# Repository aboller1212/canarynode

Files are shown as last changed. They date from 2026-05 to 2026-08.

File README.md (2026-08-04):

# CANaryNode

A CAN FD sensor node built around an STM32G474. It reads an IMU and an
environmental sensor and puts the data on a CAN bus. The firmware is
bare-metal — no HAL, no generated code, just CMSIS headers and the
reference manual. I'm building it this way because I want to understand
what every peripheral is actually doing at the register level, not call
somebody's library function and hope.

## Hardware

The custom board is a 4-layer PCB with:

- STM32G474RCT6 (Cortex-M4F, 256K flash)
- BMI270 IMU on SPI
- BME280 temperature/pressure/humidity sensor on I2C
- TI TCAN CAN FD transceiver
- USB-C

Most of the driver work was done on a Nucleo-G474RE first, bringing up one
peripheral at a time, so that porting to the real board would mostly be
remapping pins. The custom board is here now and boots.

A couple of things differ between the two: the Nucleo has a G474RET6 (512K
flash) and routes CAN to FDCAN1 on PA11/PA12, while my board uses an RCT6
and puts CAN on PB5/PB6, which is FDCAN2. That's an instance swap, not just
a pin change, so it needs its own message RAM offset.

## Layout

- `firmware/` — the STM32 firmware, where most of the work is
- `hardware/` — schematic and board files
- `docs/` — datasheets and my bring-up notes
- `tools/` — scripts

## Building

CMake + Ninja with the arm-none-eabi GCC toolchain.

    cd firmware
    cmake -B build -G Ninja
    cmake --build build

Produces `build/canary_firmware` (ELF) and a `.bin` next to it.

## Flashing

Two ways, depending on the board.

On the Nucleo I use an external ST-Link V2 on SWD (SWDIO to PA13, SWCLK to
PA14, plus GND and 3V3). The onboard ST-Link V3E doesn't work reliably from
an Apple Silicon Mac, so its USB stays unplugged and the target gets power
from the V2.

The custom board can be programmed over USB with no debugger at all. The
STM32 has a bootloader burned into ROM — jumper BOOT0 high, plug in USB-C,
and it enumerates as a DFU device:

    STM32_Programmer_CLI -c port=USB1 -w build/canary_firmware.bin 0x08000000

Pull the jumper and power cycle to run the firmware instead. That's handy,
but DFU only programs — for actual debugging I use OpenOCD as a GDB server
with arm-none-eabi-gdb over SWD.

## Status

Working and verified on hardware:

- LED blink and a TIM6 timer interrupt
- I2C master and the full BME280 driver — chip ID, calibration read and
  reassembly, and Bosch's compensation math. It streams real temperature,
  pressure and humidity, and the humidity climbs when you breathe on it.
- FDCAN at 500 kbit/s in internal loopback. A frame goes out, loops through
  the peripheral's message RAM, and comes back byte for byte.
- The custom board itself: it powers up, enumerates over USB, and takes a
  verified flash write.

Written and compiling, not yet tested on hardware:

- SPI master driver
- BMI270 driver, including the 8 KB configuration blob the sensor needs
  uploaded before it will do anything

Not working yet:

- CAN on a real bus. The MCU side is fine — I can see it transmitting
  cleanly in the registers — but the transceiver breakout I bought has a
  10k resistor on its slew rate pin that caps it well below 500 kbit/s.
  Waiting on a different transceiver.

## What's left

Port the pin assignments to the custom board, get the BMI270 talking, pack
sensor readings into CAN frames, and get those frames onto a real bus.

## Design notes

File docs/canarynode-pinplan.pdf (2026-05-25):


24/05/2026

canarynode-pinplan Project Configuration Report

## 1. Description

### 1.1. Project

Project Name | canarynode-pinplan
Board Name | custom
Generated with: | STM32CubeMX 6.15.0
Date | 05/24/2026

### 1.2. MCU

MCU Series | STM32G4
MCU Line | STM32G4x4
MCU name | STM32G474RETx
MCU Package | LQFP64
MCU Pin number | 64

### 1.3. Core(s) information

Core(s) | ARM Cortex-M4

## 2. Pinout Configuration

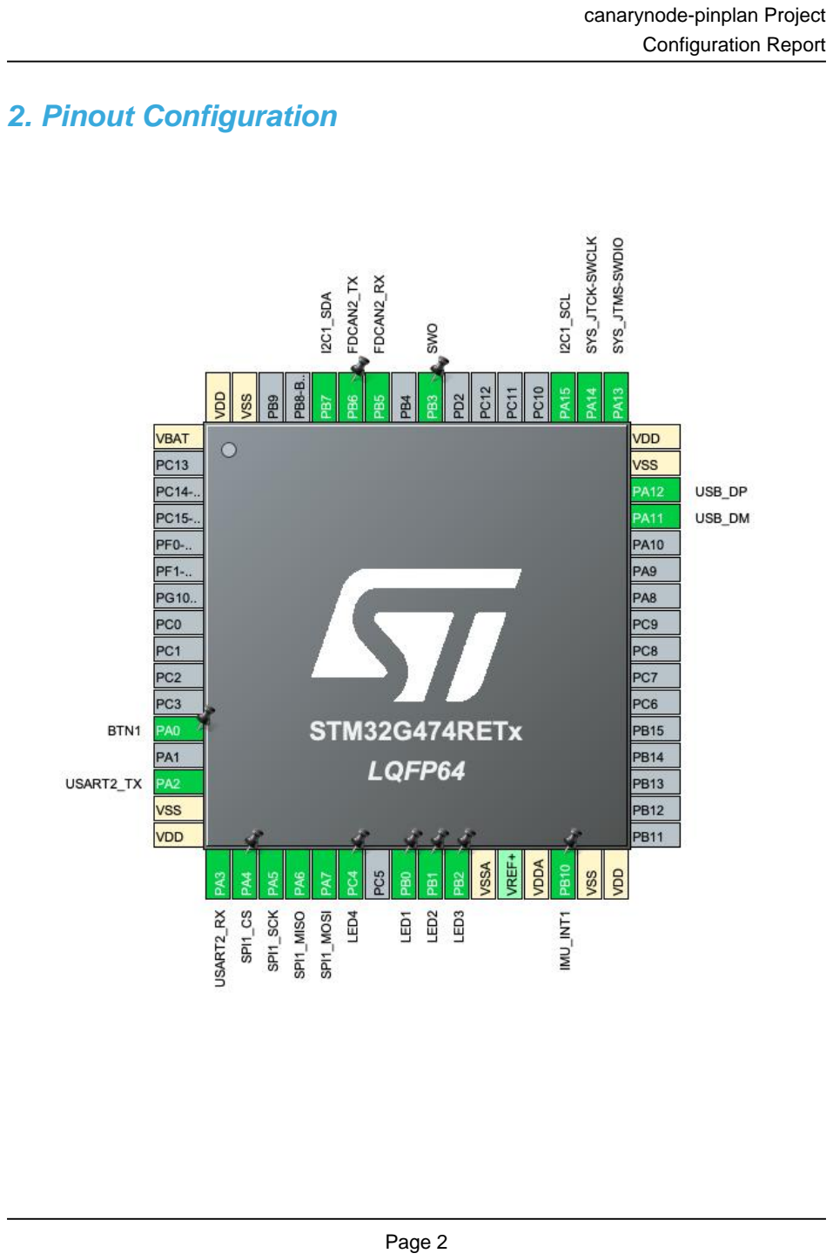
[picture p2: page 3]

## 3. Pins Configuration

Pin Number LQFP64 | Pin Name (function after reset) | Pin Type | Alternate Function(s) | Label
1 | VBAT | Power
12 | PA0 | I/O | GPIO_EXTI0 | BTN1
14 | PA2 | I/O | USART2_TX
15 | VSS | Power
16 | VDD | Power
17 | PA3 | I/O | USART2_RX
18 | PA4 * | I/O | GPIO_Output | SPI1_CS
19 | PA5 | I/O | SPI1_SCK
20 | PA6 | I/O | SPI1_MISO
21 | PA7 | I/O | SPI1_MOSI
22 | PC4 * | I/O | GPIO_Output | LED4
24 | PB0 * | I/O | GPIO_Output | LED1
25 | PB1 * | I/O | GPIO_Output | LED2
26 | PB2 * | I/O | GPIO_Output | LED3
27 | VSSA | Power
29 | VDDA | Power
30 | PB10 | I/O | GPIO_EXTI10 | IMU_INT1
31 | VSS | Power
32 | VDD | Power
45 | PA11 | I/O | USB_DM
46 | PA12 | I/O | USB_DP
47 | VSS | Power
48 | VDD | Power
49 | PA13 | I/O | SYS_JTMS-SWDIO
50 | PA14 | I/O | SYS_JTCK-SWCLK
51 | PA15 | I/O | I2C1_SCL
56 | PB3 | I/O | SYS_JTDO-SWO | SWO
58 | PB5 | I/O | FDCAN2_RX
59 | PB6 | I/O | FDCAN2_TX
60 | PB7 | I/O | I2C1_SDA
63 | VSS | Power
64 | VDD | Power

* The pin is affected with an I/O function

## 4. Clock Tree Configuration

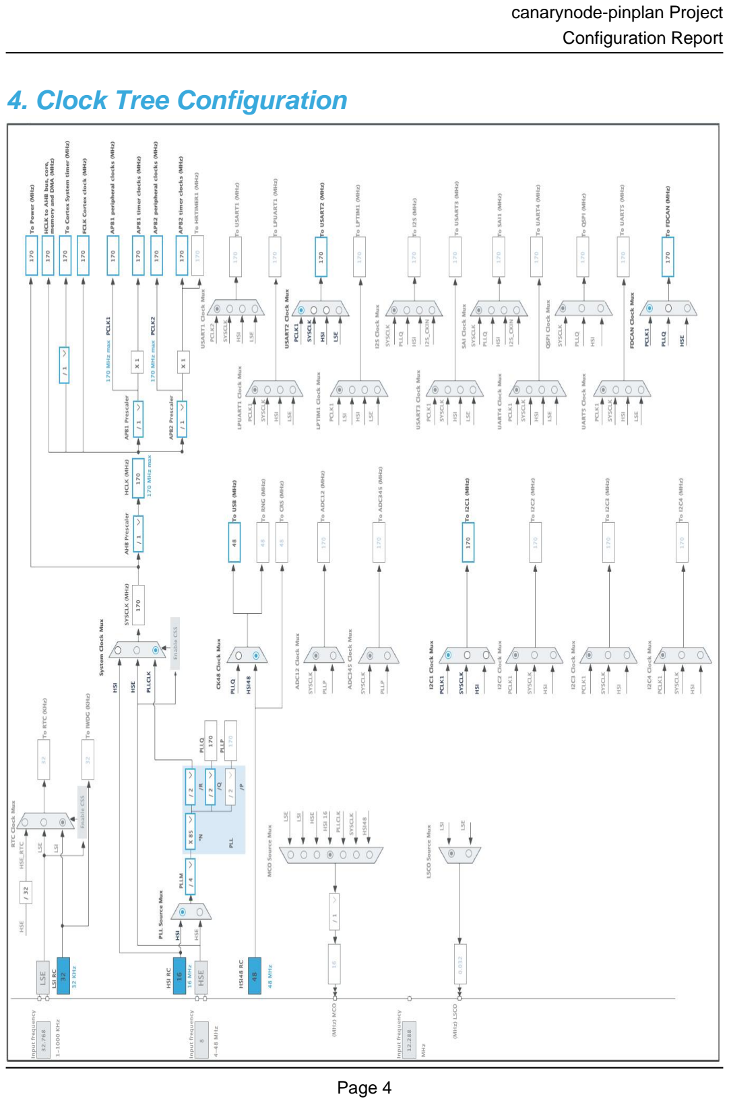
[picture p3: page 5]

## 1. Power Consumption Calculator report

### 1.1. Microcontroller Selection

Series | STM32G4
Line | STM32G4x4
MCU | STM32G474RETx
Datasheet | DS12288_Rev0

### 1.2. Parameter Selection

Temperature | 25
Vdd | 3.0

### 1.3. Battery Selection

Battery | Li-SOCL2(A3400)
Capacity | 3400.0 mAh
Self Discharge | 0.08 %/month
Nominal Voltage | 3.6 V
Max Cont Current | 100.0 mA
Max Pulse Current | 200.0 mA
Cells in series | 1
Cells in parallel | 1

### 1.4. Sequence

Step | Step1 | Step2
Mode | RUN | STOP1
Vdd | 3.0 | 3.0
Voltage Source | Battery | Battery
Range | Range1-Boost | NoRange
Fetch Type | FLASH/DualBank/ART | NA
CPU Frequency | 170 MHz | 0 Hz
Clock Configuration | HSE BYP PLL | ALL CLOCKS OFF
Clock Source Frequency | 4 MHz | 0 Hz
Peripherals
Additional Cons. | 0 mA | 0 mA
Average Current | 29.5 mA | 80.5 µA
Duration | 0.1 ms | 0.9 ms
DMIPS | 213.0 | 0.0
Ta Max | 124.25 | 129.98
Category | In DS Table | In DS Table

### 1.5. Results

Sequence Time | 1 ms | Average Current | 3.02 mA
Battery Life | 1 month, 16 days, 9 hours | Average DMIPS | 212.5 DMIPS

### 1.6. Chart

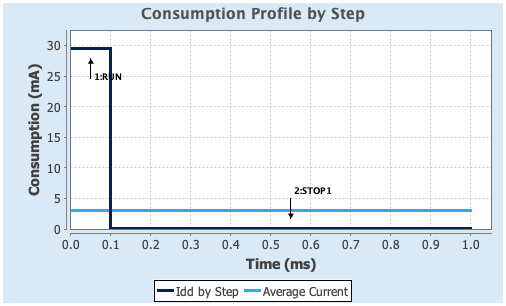
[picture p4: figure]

## 2. Software Project

### 2.1. Project Settings

Name | Value
Project Name | canarynode-pinplan
Project Folder | /Users/alexboller/STM32CubeIDE/workspace_1.19.0/canarynode-pinplan
Toolchain / IDE | STM32CubeIDE
Firmware Package Name and Version | STM32Cube FW_G4 V1.6.3
Application Structure | Advanced
Generate Under Root | Yes
Do not generate the main() | No
Minimum Heap Size | 0x200
Minimum Stack Size | 0x400

### 2.2. Code Generation Settings

Name | Value
STM32Cube MCU packages and embedded software | Copy only the necessary library files
Generate peripheral initialization as a pair of '.c/.h' files | No
Backup previously generated files when re-generating | No
Keep User Code when re-generating | Yes
Delete previously generated files when not re-generated | Yes
Set all free pins as analog (to optimize the power consumption) | No
Enable Full Assert | No

### 2.3. Advanced Settings - Generated Function Calls

Rank | Function Name | Peripheral Instance Name
1 | SystemClock_Config | RCC
2 | MX_GPIO_Init | GPIO
3 | MX_I2C1_Init | I2C1
4 | MX_SPI1_Init | SPI1
5 | MX_USART2_UART_Init | USART2
6 | MX_USB_PCD_Init | USB
7 | MX_FDCAN2_Init | FDCAN2

## 3. Peripherals and Middlewares Configuration

### 3.1. FDCAN2

mode: Activated
3.1.1. Parameter Settings:

Basic Parameters:

Clock Divider | Divide kernel clock by 1
Frame Format | Classic mode
Mode | Normal mode
Auto Retransmission | Disable
Transmit Pause | Disable
Protocol Exception | Disable
Nominal Sync Jump Width | 1
Data Prescaler | 1
Data Sync Jump Width | 1
Data Time Seg1 | 1
Data Time Seg2 | 1
Std Filters Nbr | 0
Ext Filters Nbr | 0
Tx Fifo Queue Mode | FIFO mode
Bit Timings Parameters:
Nominal Prescaler | 16
Nominal Time Quantum | 94.11764705882354 *
Nominal Time Seg1 | 1
Nominal Time Seg2 | 1
Nominal Time for one Bit | 282 *
Nominal Baud Rate | 3541666 *

### 3.2. I2C1

I2C: I2C
3.2.1. Parameter Settings:

Timing configuration:

Custom Timing | Disabled
I2C Speed Mode | Standard Mode
I2C Speed Frequency (KHz) | 100
Rise Time (ns) | 100
Fall Time (ns) | 100

Coefficient of Digital Filter | 0
Analog Filter | Enabled
Timing | 0x40B285C2 *
Slave Features:
Clock No Stretch Mode | Disabled
General Call Address Detection | Disabled
Primary Address Length selection | 7-bit
Dual Address Acknowledged | Disabled
Primary slave address | 0

### 3.3. RCC

3.3.1. Parameter Settings:

System Parameters:

VDD voltage (V) | 3.3
Instruction Cache | Enabled
Prefetch Buffer | Disabled
Data Cache | Enabled
Flash Latency(WS) | 4 WS (5 CPU cycle)
RCC Parameters:
HSI Calibration Value | 64
HSE Startup Timout Value (ms) | 100
LSE Startup Timout Value (ms) | 5000
Power Parameters:
Power Regulator Voltage Scale | Power Regulator Voltage Scale 1 boost
Peripherals Clock Configuration:
Generate the peripherals clock configuration | TRUE

### 3.4. SPI1

Mode: Full-Duplex Master
3.4.1. Parameter Settings:

Basic Parameters:

Frame Format | Motorola
Data Size | 8 Bits *
First Bit | MSB First
Clock Parameters:

Prescaler (for Baud Rate) | 32 *
Baud Rate | 5.3125 MBits/s *
Clock Polarity (CPOL) | High *
Clock Phase (CPHA) | 2 Edge *
Advanced Parameters:
CRC Calculation | Disabled
NSS Signal Type | Software

### 3.5. SYS

Debug: Trace Asynchronous Sw
Timebase Source: SysTick
mode: save power of non-active UCPD - deactive Dead Battery pull-up

### 3.6. USART2

Mode: Asynchronous
3.6.1. Parameter Settings:

Basic Parameters:

Baud Rate | 115200
Word Length | 8 Bits (including Parity)
Parity | None
Stop Bits | 1
Advanced Parameters:
Data Direction | Receive and Transmit
Over Sampling | 16 Samples
Single Sample | Disable
ClockPrescaler | 1
Fifo Mode | Disable
Txfifo Threshold | 1 eighth full configuration
Rxfifo Threshold | 1 eighth full configuration
Advanced Features:
Auto Baudrate | Disable
TX Pin Active Level Inversion | Disable
RX Pin Active Level Inversion | Disable
Data Inversion | Disable
TX and RX Pins Swapping | Disable
Overrun | Enable
DMA on RX Error | Enable

MSB First | Disable

### 3.7. USB

mode: Device (FS)
3.7.1. Parameter Settings:

Basic Parameters:

Speed | Full Speed 12MBit/s
Physical interface | Internal Phy
Sof Enable | Disabled
Power Parameters:
Low Power | Disabled
Link Power Management | Disabled
Battery Charging | Disabled

* User modified value

## 4. System Configuration

### 4.1. GPIO configuration

IP | Pin | Signal | GPIO mode | GPIO pull/up pull down | Max Speed | User Label
FDCAN2 | PB5 | FDCAN2_RX | Alternate Function Push Pull | No pull-up and no pull-down | Low
| PB6 | FDCAN2_TX | Alternate Function Push Pull | No pull-up and no pull-down | Low
I2C1 | PA15 | I2C1_SCL | Alternate Function Open Drain | No pull-up and no pull-down | Low
| PB7 | I2C1_SDA | Alternate Function Open Drain | No pull-up and no pull-down | Low
SPI1 | PA5 | SPI1_SCK | Alternate Function Push Pull | No pull-up and no pull-down | Low
| PA6 | SPI1_MISO | Alternate Function Push Pull | No pull-up and no pull-down | Low
| PA7 | SPI1_MOSI | Alternate Function Push Pull | No pull-up and no pull-down | Low
SYS | PA13 | SYS_JTMS-SWDIO | n/a | n/a | n/a
| PA14 | SYS_JTCK-SWCLK | n/a | n/a | n/a
| PB3 | SYS_JTDO-SWO | n/a | n/a | n/a | SWO
USART2 | PA2 | USART2_TX | Alternate Function Push Pull | No pull-up and no pull-down | Low
| PA3 | USART2_RX | Alternate Function Push Pull | No pull-up and no pull-down | Low
USB | PA11 | USB_DM | n/a | n/a | n/a
| PA12 | USB_DP | n/a | n/a | n/a
GPIO | PA0 | GPIO_EXTI0 | External Interrupt Mode with Falling edge trigger detection | Pull-up * | n/a | BTN1
| PA4 | GPIO_Output | Output Push Pull | No pull-up and no pull-down | Low | SPI1_CS
| PC4 | GPIO_Output | Output Push Pull | No pull-up and no pull-down | Low | LED4
| PB0 | GPIO_Output | Output Push Pull | No pull-up and no pull-down | Low | LED1
| PB1 | GPIO_Output | Output Push Pull | No pull-up and no pull-down | Low | LED2
| PB2 | GPIO_Output | Output Push Pull | No pull-up and no pull-down | Low | LED3
| PB10 | GPIO_EXTI10 | External Interrupt Mode with Falling edge trigger detection | Pull-up * | n/a | IMU_INT1

### 4.2. DMA configuration

nothing configured in DMA service

### 4.3. NVIC configuration

4.3.1. NVIC
Interrupt Table | Enable | Preenmption Priority | SubPriority
Non maskable interrupt | true | 0 | 0
Hard fault interrupt | true | 0 | 0
Memory management fault | true | 0 | 0
Prefetch fault, memory access fault | true | 0 | 0
Undefined instruction or illegal state | true | 0 | 0
System service call via SWI instruction | true | 0 | 0
Debug monitor | true | 0 | 0
Pendable request for system service | true | 0 | 0
System tick timer | true | 15 | 0
EXTI line[15:10] interrupts | true | 0 | 0
PVD/PVM1/PVM2/PVM3/PVM4 interrupts through EXTI lines 16/38/39/40/41 | unused
Flash global interrupt | unused
RCC global interrupt | unused
EXTI line0 interrupt | unused
USB high priority interrupt remap | unused
USB low priority interrupt remap | unused
I2C1 event interrupt / I2C1 wake-up interrupt through EXTI line 23 | unused
I2C1 error interrupt | unused
SPI1 global interrupt | unused
USART2 global interrupt / USART2 wake-up interrupt through EXTI line 26 | unused
FPU global interrupt | unused
FDCAN2 interrupt 0 | unused
FDCAN2 interrupt 1 | unused
4.3.2. NVIC Code generation
Enabled interrupt Table | Select for init sequence ordering | Generate IRQ handler | Call HAL handler
Non maskable interrupt | false | true | false
Hard fault interrupt | false | true | false
Memory management fault | false | true | false
Prefetch fault, memory access fault | false | true | false
Undefined instruction or illegal state | false | true | false
System service call via SWI instruction | false | true | false
Debug monitor | false | true | false
Pendable request for system service | false | true | false

Enabled interrupt Table | Select for init sequence ordering | Generate IRQ handler | Call HAL handler
System tick timer | false | true | true
EXTI line[15:10] interrupts | false | true | true

* User modified value

## 5. System Views

5.1. Category view
5.1.1. Current

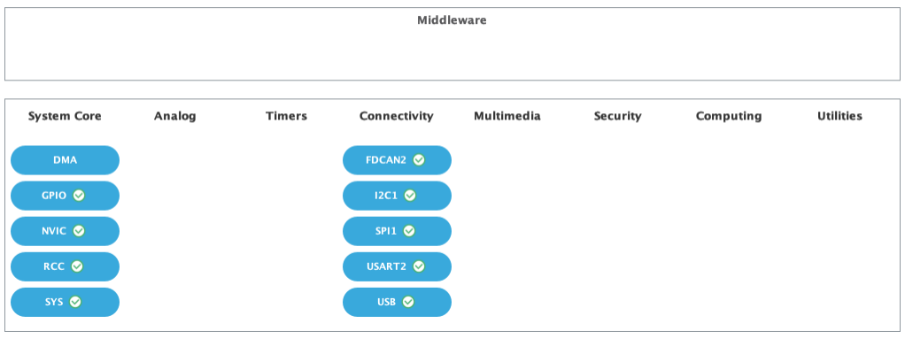
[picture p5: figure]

## 6. Docs & Resources

Type | Link
BSDL files | https://www.st.com/resource/en/bsdl_model/stm32g4_bsdl.zip
IBIS models | https://www.st.com/resource/en/ibis_model/stm32g4_ibis.zip
System View Description | https://www.st.com/resource/en/svd/stm32g4_svd.zip
Presentations | https://www.st.com/resource/en/product_presentation/stm32-stm8_embedded_software_solutions.pdf
Presentations | https://www.st.com/resource/en/product_presentation/stm32_eval-tools_portfolio.pdf
Presentations | https://www.st.com/resource/en/product_presentation/stm32_stm8_functi onal-safety-packages.pdf
Presentations | https://www.st.com/resource/en/product_presentation/stm32-usb-c-pd-solutions-presentation.pdf
Presentations | https://www.st.com/resource/en/product_presentation/stm32-stm8_software_development_tools.pdf
Presentations | https://www.st.com/resource/en/product_presentation/microcontrollers-stm32-family-overview.pdf
Presentations | https://www.st.com/resource/en/product_presentation/microcontrollers-stm32g4-series-product-overview.pdf
Brochures | https://www.st.com/resource/en/brochure/products-and-solutions-for-plcs-and-smart-i-os.pdf
Brochures | https://www.st.com/resource/en/brochure/expansion-boards-for-intelligent-power-switches.pdf
Flyers | https://www.st.com/resource/en/flyer/flstm32g4.pdf
Flyers | https://www.st.com/resource/en/flyer/flstm32nucleo.pdf
Flyers | https://www.st.com/resource/en/flyer/flstm32trust.pdf
Flyers | https://www.st.com/resource/en/flyer/flpowerstbd.pdf
Flyers | https://www.st.com/resource/en/flyer/fldpstpfc11120.pdf
Security Bulletin | https://www.st.com/resource/en/technical_note/tn1489-security-bulletin- tn1489stpsirt-physical-attacks-on-stm32-and-stm32cube-firmware-

| stmicroelectronics.pdf
Application Notes | https://www.st.com/resource/en/application_note/an1709-emc-design-guide-for-stm8-stm32-and-legacy-mcus-stmicroelectronics.pdf
Application Notes | https://www.st.com/resource/en/application_note/an3126-audio-and-waveform-generation-using-the-dac-in-stm32-products-stmicroelectronics.pdf
Application Notes | https://www.st.com/resource/en/application_note/an3155-usart-protocol-used-in-the-stm32-bootloader-stmicroelectronics.pdf
Application Notes | https://www.st.com/resource/en/application_note/an3156-usb-dfu-protocol-used-in-the-stm32-bootloader-stmicroelectronics.pdf
Application Notes | https://www.st.com/resource/en/application_note/an4221-i2c-protocol-used-in-the-stm32-bootloader-stmicroelectronics.pdf
Application Notes | https://www.st.com/resource/en/application_note/an4232-getting-started-with-analog-comparators-for-stm32f3-series-and-stm32g4-series-devices-stmicroelectronics.pdf
Application Notes | https://www.st.com/resource/en/application_note/an4286-spi-protocol-used-in-the-stm32-bootloader-stmicroelectronics.pdf
Application Notes | https://www.st.com/resource/en/application_note/an4296-use-stm32f3stm32g4-ccm-sram-with-iar-embedded-workbench-keil-mdkarm-stmicroelectronics-stm32cubeide-and-other-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
Application Notes | https://www.st.com/resource/en/application_note/an4539-hrtim-cookbook-stmicroelectronics.pdf
Application Notes | https://www.st.com/resource/en/application_note/an4655-virtually-increasing-the-number-of-serial-communication-peripherals-in-stm32-applications-stmicroelectronics.p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
Application Notes | https://www.st.com/resource/en/application_note/an4750-handling-of-soft-errors-in-stm32-applications-stmicroelectronics.pdf
Application Notes | https://www.st.com/resource/en/application_note/an4776-generalpurpose-timer-cookbook-for-stm32-microcontrollers-stmicroelectronics.pdf
Application Notes | https://www.st.com/resource/en/application_note/an4803-highspeed-si-simulations-using-ibis-and-boardlevel-simulations-using-hyperlynx-si-on-stm32-mcus-and-mpus-stmic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

Application Notes | https://www.st.com/resource/en/application_note/an4989-stm32-microcontroller-debug-toolbox-stmicroelectronics.pdf
Application Notes | https://www.st.com/resource/en/application_note/an5027-interfacing-pdm-digital-microphones-using-stm32-mcus-and-mpus-stmicroelectronics.pdf
Application Notes | https://www.st.com/resource/en/application_note/an5093-getting-started-with-stm32g4-series--hardware-development-boards-stmicroelectronics.pdf
Application Notes | https://www.st.com/resource/en/application_note/an5306-operational-amplifier-opamp-usage-in-stm32g4-series-stmicroelectronics.pdf
Application Notes | https://www.st.com/resource/en/application_note/an5310-guideline-for-using-analog-features-of-stm32g4-series-versus-stm32f3-series-devices-stmicroelectronics.pdf
Application Notes | https://www.st.com/resource/en/application_note/an5315-stm32cube-firmware-examples-for-stm32g4-series-stmicroelectronics.pdf
Application Notes | https://www.st.com/resource/en/application_note/an5346-stm32g4-adc-use-tips-and-recommendations-stmicroelectronics.pdf
Application Notes | https://www.st.com/resource/en/application_note/an5094-migrating-between-stm32f334303-lines-and-stm32g431xxg474xxg491xx-microcontrollers-stmicroelectronics.pdf
Application Notes | https://www.st.com/resource/en/application_note/an5738-stm32g4-series-lifetime-estimates-stmicroelectronics.pdf
Application Notes | https://www.st.com/resource/en/application_note/an4760-quadspi-interface-on-stm32-microcontrollers-and-microprocessors--stmicroelectronics.pdf
Application Notes | https://www.st.com/resource/en/application_note/an4899-stm32-microcontroller-gpio-hardware-settings-and-lowpower-consumption-stmicroelectronics.pdf
Application Notes | https://www.st.com/resource/en/application_note/an5612-esd-protection-of-stm32-mcus-and-mpus-stmicroelectronics.pdf
Application Notes | https://www.st.com/resource/en/application_note/an5788-stm32-digital-power-pid-and-iir-filters-for-smps-control-design-and-comparison-on-bg414edpow1-discovery-kit-st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
Application Notes | https://www.st.com/resource/en/application_note/an4991-how-to-wake-

| up-an-stm32-microcontroller-from-lowpower-mode-with-the-usart-or-the-lpuart-stmicroelectronics.pdf
Application Notes | https://www.st.com/resource/en/application_note/an4838-introduction-to-memory-protection-unit-management-on-stm32-mcus-stmicroelectronics.pdf
Application Notes | https://www.st.com/resource/en/application_note/an5325-how-to-use-the-cordic-to-perform-mathematical-functions-on-stm32-mcus-stmicroelectronics.pdf
Application Notes | https://www.st.com/resource/en/application_note/an5225-introduction-to-usb-typec-power-delivery-for-stm32-mcus-and-mpus-stmicroelectronics.pdf
Application Notes | https://www.st.com/resource/en/application_note/an4894-how-to-use-eeprom-emulation-on-stm32-mcus-stmicroelectronics.pdf
Application Notes | https://www.st.com/resource/en/application_note/an5537-how-to-use-adc-oversampling-techniques-to-improve-signaltonoise-ratio-on-stm32-mcus-stmicroelectronics.pdf
Application Notes | https://www.st.com/resource/en/application_note/an5036-guidelines-for-thermal-management-on-stm32-applications-stmicroelectronics.pdf
Application Notes | https://www.st.com/resource/en/application_note/an5405-how-to-use-fdcan-bootloader-protocol-on-stm32-mcus-stmicroelectronics.pdf
Application Notes | https://www.st.com/resource/en/application_note/an5978-introduction-to-mb1971-llc-hat-12-v-to-75-v1-a-for-f334-g474-nucleo-board-stmicroelectronics.pdf
Application Notes | https://www.st.com/resource/en/application_note/an5690-how-to-use-vrefbuf-peripheral-on-stm32-mcus-and-mpus-stmicroelectronics.pdf
Application Notes | https://www.st.com/resource/en/application_note/an4230-introduction-to-random-number-generation-validation-using-the-nist-statistical-test-suite-for-stm32-mcus-and-m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
Application Notes | https://www.st.com/resource/en/application_note/an2548-introduction-to-dma-controller-for-stm32-mcus-stmicroelectronics.pdf
Application Notes | https://www.st.com/resource/en/application_note/an4013-introduction-to-timers-for-stm32-mcus-stmicroelectronics.pdf
Application Notes | https://www.st.com/resource/en/application_note/an4277-how-to-use-

| pwm-shutdown-for-motor-control-and-digital-power-conversion-on-stm32-mcus-stmicroelectronics.pdf
Application Notes | https://www.st.com/resource/en/application_note/an4635-how-to-optimize-lpuart-power-consumption-on-stm32-mcus-stmicroelectronics.pdf
Application Notes | https://www.st.com/resource/en/application_note/an4759-introduction-to-using-the-hardware-realtime-clock-rtc-and-the-tamper-management-unit-tamp-with-stm32-mcus-stmi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
Application Notes | https://www.st.com/resource/en/application_note/an4908-getting-started-with-usart-automatic-baud-rater-detection-for-stm32-mcus-stmicroelectronics.pdf
Application Notes | https://www.st.com/resource/en/application_note/an5156-introduction-to-security-for-stm32-mcus-stmicroelectronics.pdf
Application Notes | https://www.st.com/resource/en/application_note/an5224-introduction-to-dmamux-for-stm32-mcus-stmicroelectronics.pdf
Application Notes | https://www.st.com/resource/en/application_note/an5543-guidelines-for-enhanced-spi-communication-on-stm32-mcus-and-mpus-stmicroelectronics.pdf
Application Notes | https://www.st.com/resource/en/application_note/an5348-introduction-to-fdcan-peripherals-for-stm32-mcus-stmicroelectronics.pdf
Application Notes | https://www.st.com/resource/en/application_note/cd00211314-how-to-optimize-the-adc-accuracy-in-the-stm32-mcus-stmicroelectronics.pdf
Application Notes | https://www.st.com/resource/en/application_note/an2639-soldering-recommendations-and-package-information-for-leadfree-ecopack2-mcus-and-mpus-stmicroelectronics.pdf
Application Notes | https://www.st.com/resource/en/application_note/an4566-how-to-extend-the-dac-performance-on-stm32-mcus-stmicroelectronics.pdf
Application Notes | https://www.st.com/resource/en/application_note/an5647-the-goertzel-algorithm-to-compute-individual-terms-of-the-discrete-fourier-transform-dft-in-stm32-products-stm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
Application Notes | https://www.st.com/resource/en/application_note/an2606-introduction-to-system-memory-boot-mode-on-stm32-mcus-stmicroelectronics.pdf
Application Notes | https://www.st.com/resource/en/application_note/an4435-guidelines-for-

for related Tools & Software | obtaining-ulcsaiec-607301603351-class-b-certification-in-any-stm32-application-stmicroelectronics.pdf
Application Notes for related Tools & Software | https://www.st.com/resource/en/application_note/an4657-stm32-inapplication-programming-iap-using-the-usart-stmicroelectronics.pdf
Application Notes for related Tools & Software | https://www.st.com/resource/en/application_note/an4841-digital-signal-processing-for-stm32-microcontrollers-using-cmsis-stmicroelectronics.pdf
Application Notes for related Tools & Software | https://www.st.com/resource/en/application_note/an5056-integration-guide-for-the-xcubesbsfu-stm32cube-expansion-package-stmicroelectronics.pdf
Application Notes for related Tools & Software | https://www.st.com/resource/en/application_note/an5305-digital-filter-implementation-with-the-fmac-using-stm32cubeg4-mcu-package-stmicroelectronics.pdf
Application Notes for related Tools & Software | https://www.st.com/resource/en/application_note/an5315-stm32cube-firmware-examples-for-stm32g4-series-stmicroelectronics.pdf
Application Notes for related Tools & Software | https://www.st.com/resource/en/application_note/an5345-highbrightness-rgb-led-control-using-the-bg474edpow1-discovery-kit-stmicroelectronics.pdf
Application Notes for related Tools & Software | https://www.st.com/resource/en/application_note/an5360-getting-started-with-projects-based-on-the-stm32mp1-series-in-stm32cubeide-stmicroelectronics.pdf
Application Notes for related Tools & Software | https://www.st.com/resource/en/application_note/an5361-getting-started-with-projects-based-on-dualcore-stm32h7-microcontrollers-in-stm32cubeide-stmicroelectronics.pd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
Application Notes for related Tools & Software | https://www.st.com/resource/en/application_note/an5394-getting-started-with-projects-based-on-the-stm32l5-series-in-stm32cubeide-stmicroelectronics.pdf
Application Notes for related Tools & Software | https://www.st.com/resource/en/application_note/an5418-how-to-build-a-simple-usbpd-sink-application-with-stm32cubemx-stmicroelectronics.pdf

Application Notes
for related Tools

https://www.st.com/resource/en/application_note/an5426-migratinggraphics-middleware-projects-from-stm32cubemx-540-to-stm32cubemx-

& Software | 550-stmicroelectronics.pdf
Application Notes for related Tools & Software | https://www.st.com/resource/en/application_note/an5464-position-control-of-a-threephase-permanent-magnet-motor-using-xcubemcsdk-or-xcubemcsdkful-stmicroelectronics.p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
Application Notes for related Tools & Software | https://www.st.com/resource/en/application_note/an5564-getting-started-with-projects-based-on-dualcore-stm32wl-microcontrollers-in-stm32cubeide-stmicroelectronics.pd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
Application Notes for related Tools & Software | https://www.st.com/resource/en/application_note/an5698-adapting-the-xcubestl-functional-safety-package-for-stm32-iec-61508-compliant-to-other-safety-standards-stmicr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
Application Notes for related Tools & Software | https://www.st.com/resource/en/application_note/an5731-stm32cubemx-and-stm32cubeide-threadsafe-solution-stmicroelectronics.pdf
Application Notes for related Tools & Software | https://www.st.com/resource/en/application_note/an5785-boost-voltage-mode-on-bg474edpow1-discovery-kit-stmicroelectronics.pdf
Application Notes for related Tools & Software | https://www.st.com/resource/en/application_note/an5788-stm32-digital-power-pid-and-iir-filters-for-smps-control-design-and-comparison-on-bg414edpow1-discovery-kit-st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
Application Notes for related Tools & Software | https://www.st.com/resource/en/application_note/an4502-stm32-smbuspmbus-expansion-package-for-stm32cube-stmicroelectronics.pdf
Application Notes for related Tools & Software | https://www.st.com/resource/en/application_note/an5952-how-to-use-cmake-in-stm32cubeide-stmicroelectronics.pdf
Application Notes for related Tools & Software | https://www.st.com/resource/en/application_note/an4635-how-to-optimize-lpuart-power-consumption-on-stm32-mcus-stmicroelectronics.pdf
Application Notes for related Tools & Software | https://www.st.com/resource/en/application_note/an5054-how-to-perform-secure-programming-using-stm32cubeprogrammer-stmicroelectronics.pdf
Application Notes for related Tools & Software | https://www.st.com/resource/en/application_note/an5496-guidelines-for-the-buck-voltage-mode-on-the-bg474edpow1-discovery-kit-stmicroelectronics.pdf

Application Notes for related Tools & Software | https://www.st.com/resource/en/application_note/an5497-introduction-to-the-buck-current-mode-with-the-bg474edpow1-discovery-kit-stmicroelectronics.pdf
Application Notes for related Tools & Software | https://www.st.com/resource/en/application_note/an6179-how-to-integrate-the-stl-firmware-into-a-time-critical-user-application-stmicroelectronics.pdf
Application Notes for related Tools & Software | https://www.st.com/resource/en/application_note/an6127-getting-started-with-stm32h7rx7sx-mcus-in-stm32cubeide-stmicroelectronics.pdf
Application Notes for related Tools & Software | https://www.st.com/resource/en/application_note/an6265-getting-started-with-stm32n6-mcus-in-stm32cubeide-stmicroelectronics.pdf
Application Notes for related Tools & Software | https://www.st.com/resource/en/application_note/an6382-introduction-to-swd-multidrop-for-stm32-with-stlink-stmicroelectronics.pdf
Errata Sheets | https://www.st.com/resource/en/errata_sheet/es0430-stm32g471xx473xx474xx483xx484xx-device-errata-stmicroelectronics.pdf
Datasheet | https://www.st.com/resource/en/datasheet/dm00431551.pdf
Programming Manuals | https://www.st.com/resource/en/programming_manual/pm0214-stm32-cortexm4-mcus-and-mpus-programming-manual-stmicroelectronics.pdf
Reference Manuals | https://www.st.com/resource/en/reference_manual/rm0440-stm32g4-series-advanced-armbased-32bit-mcus-stmicroelectronics.pdf
Technical Notes & Articles | https://www.st.com/resource/en/technical_note/tn1163-description-of-wlcsp-for-microcontrollers-and-recommendations-for-its-use-stmicroelectronics.pdf
Technical Notes & Articles | https://www.st.com/resource/en/technical_note/tn1204-tape-and-reel-shipping-media-for-stm32-microcontrollers-in-bga-packages-stmicroelectronics.pdf
Technical Notes & Articles | https://www.st.com/resource/en/technical_note/tn1205-tape-and-reel-shipping-media-for-stm8-and-stm32-microcontrollers-in-fpn-packages-stmicroelectronics.pdf
Technical Notes & Articles | https://www.st.com/resource/en/technical_note/tn1206-tape-and-reel-shipping-media-for-stm8-and-stm32-microcontrollers-in-qfp-packages-stmicroelectronics.pdf

Technical Notes & Articles | https://www.st.com/resource/en/technical_note/tn1207-tape-and-reel-shipping-media-for-stm8-and-stm32-microcontrollers-in-so-packages-stmicroelectronics.pdf
Technical Notes & Articles | https://www.st.com/resource/en/technical_note/tn1208-tape-and-reel-shipping-media-for-stm8-and-stm32-microcontrollers-in-tssop-and-ssop-packages-stmicroelectronics.p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
Technical Notes & Articles | https://www.st.com/resource/en/technical_note/tn1433-reference-device-marking-schematics-for-stm32-microcontrollers-and-microprocessors-stmicroelectronics.pdf
User Manuals | https://www.st.com/resource/en/user_manual/um3167-stm32g4-series-ulcsaiec-607301603351-selftest-library-user-guide-stmicroelectronics.pdf

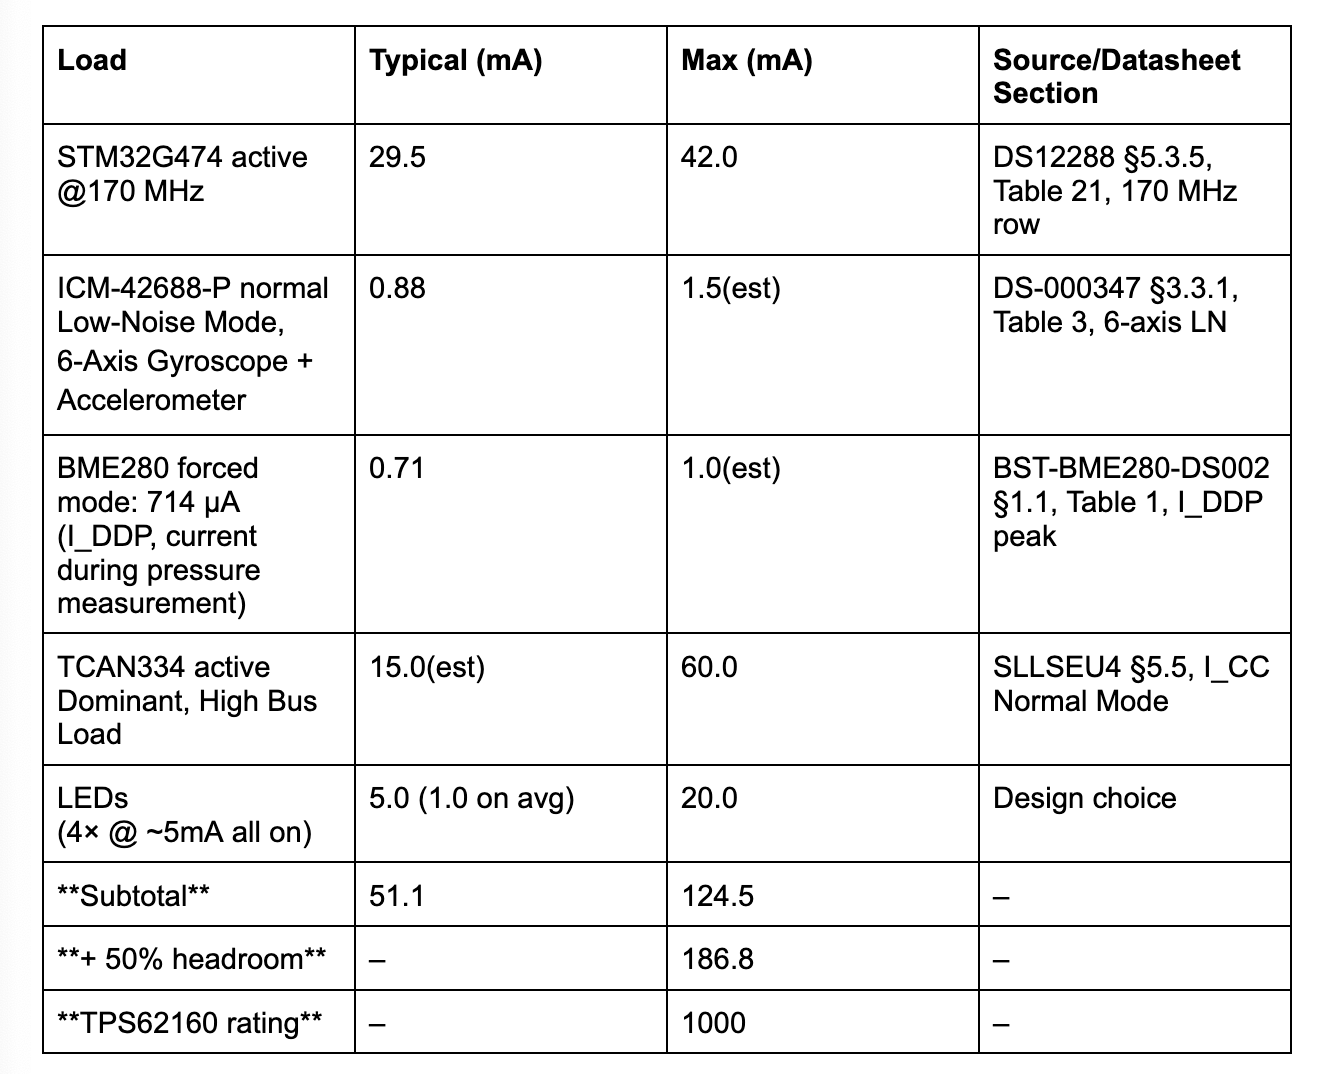
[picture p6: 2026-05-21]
docs/captures/Power Tree - canary node.png

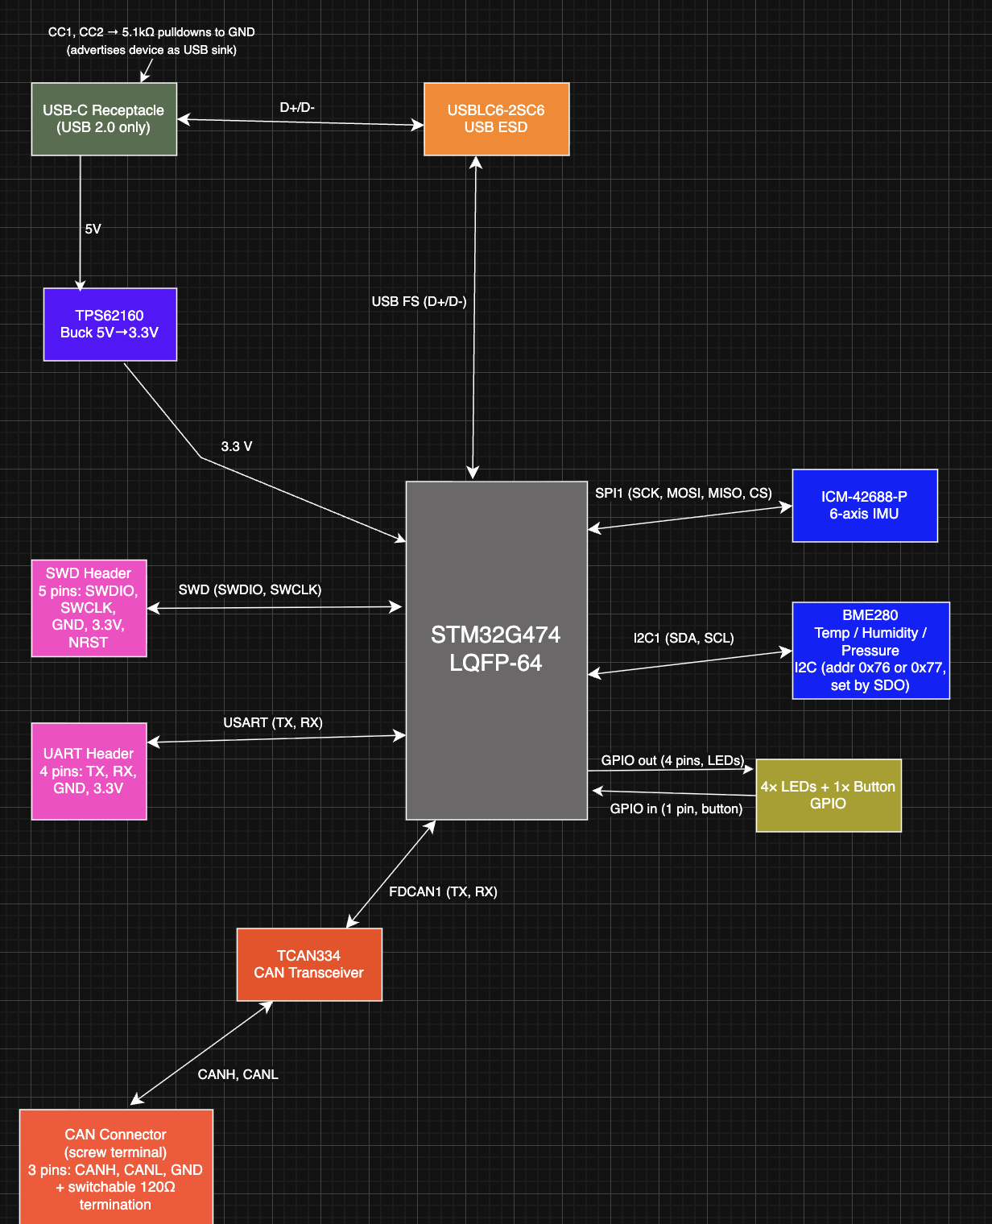
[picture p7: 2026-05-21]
docs/captures/FlowChart - canary node.png

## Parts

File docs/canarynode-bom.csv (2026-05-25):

Refdes Prefix | Value | Description | MFR Part Number | Manufacturer | LCSC P/N | JLCPCB Tier | Package | Quantity | Unit Price ($) | Footprint | Notes
U1 | TPS62160DGKR | 3V-17V to 3.3V buck converter, 1 A | TPS62160DGKR | Texas Instruments | C60726 | Extended | VSON-8 | 9687 | 1.31 | Package_SO:MSOP-8_3x3mm_P0.65mm | Powers entire 3.3V rail
L1 | 3.3uH | Power inductor | XFL3012-332MEC | Coilcraft | C3911580 | Extended | 3.0x3.0mm | 126 | 1.01 | Coilcraft_Local:IND_XFL3012_COC
C1 | 10µF | 10V, X5R, 0603 | CL10A106KP8NNNC | Samsung | C19702 | Basic | 0603 | 16300000 | 0.01 | Capacitor_SMD:C_0603_1608Metric | Buck output
C2 | 22µF | 16V, X5R, 0603 | CL10A226MQ8NRNC | Samsung | C59461 | Basic | 0603 | 14100000 | 0.01 | Capacitor_SMD:C_0603_1608Metric | Buck input
R1 | 562kΩ | 0402, 1% | 0402WGF5623TCE | Uni-Royal | C48838 | Extended | 0402 | 28178 |  | Resistor_SMD:R_0402_1005Metric | Buck FB divider
R2 | 180kΩ | 0402, 1% | 0402WGF1803TCE | Uni-Royal | C25760 | Extended | 0402 | 720861 |  | Resistor_SMD:R_0402_1005Metric | Buck FB divider
R3 | 100kΩ | 0402, 1% | 0402WGF1003TCE | Uni-Royal | C25741 | Basic | 0402 | 4092328 |  | Resistor_SMD:R_0402_1005Metric | Buck FB divider
U2 | STM32G474RET6 | 170 MHz Cortex-M4 MCU, 512 KB Flash, FDCAN, USB FS | STM32G474RET6 | STMicroelectronics | C521608 | Extended | LQFP-64 | 1 | 3.69 | Package_QFP:LQFP-64_10x10mm_P0.5mm | Main MCU - pinout locked in CubeMX
SW1 | SW_Push | Reset button | HX 3x4x2-2P-1.6N | hanxia | C49234124 | Extended | SMD 3x4mm 2-pin | 101172 | 0.01 | Button_Switch_SMD:SW_SPST_TL3342 | Cat 3 (convention pick)
D1 | ESDZL5-1F4 | USB ESD | ESDZL5-1F4 | STMicroelectronics | C2970171 | Extended | 0201 | 3637 | 0.01 | Diode_SMD:D_0201_0603Metric | Cat 2 (Nucleo reference exact match)
J1 | Conn_01x02 | 2-pin 2.54mm header | HX PZ2.54-1x2P TP-YQ | hanxia | C41417359 | Extended | 1x2 2.54mm | 4719 | 0.01 | Connector_PinHeader_2.54mm:PinHeader_1x02_P2.54mm_Vertical
C3,C5,C6 | 1µF | 0603, X5R, 50V, ±10% | CL10A105KB8NNNC | Samsung | C15849 | Basic | 0603 |  |  | Capacitor_SMD:C_0603_1608Metric
C12 | 4.7µF | 0603, X5R, 16V, ±10% | CL10A475KO8NNNC | Samsung | C19666 | Basic | 0603 |  |  | Capacitor_SMD:C_0603_1608Metric
C4,C7-C11,C13 | 100nF | 0402, X7R, 16V, ±10% | CL05B104KO5NNNC | Samsung | C1525 | Basic | 0402 |  |  | Capacitor_SMD:C_0402_1005Metric
R4-R6 | 0Ω | 0402, 1% (jumper) | 0402WGF0000TCE | Uni-Royal | C17168 | Basic | 0402 |  |  | Resistor_SMD:R_0402_1005Metric
R7 | 10kΩ | 0402, 1%, 50V | 0402WGF1002TCE | Uni-Royal | C25744 | Basic | 0402 |  |  | Resistor_SMD:R_0402_1005Metric
J2 | USB_C_Receptacle_USB2.0_16P | USB-C receptacle, USB 2.0, 16-pin SMD | TYPE-C-31-M-12 | Korean Hroparts Elec | C165948 | Basic | SMD |  |  | Connector_USB:USB_C_Receptacle_HRO_TYPE-C-31-M-12
U3 | USBLC6-2P6 | USB 2.0 ESD protection | USBLC6-2P6 | STMicroelectronics | C15999 | Extended | SOT-666 |  |  | Package_TO_SOT_SMD:SOT-666
R8,R9 | 5.1kΩ | 0402, 1% | 0402WGF5101TCE | Uni-Royal | C25905 | Basic | 0402 | 6333007 |  | Resistor_SMD:R_0402_1005Metric | USB-C CC pulldowns
C14 | 100nF | 0402, X7R, 16V, ±10% | CL05B104KO5NNNC | Samsung | C1525 | Basic | 0402 |  |  | Capacitor_SMD:C_0402_1005Metric
C15 | 10µF | 10V, X5R, 0603 | CL10A106KP8NNNC | Samsung | C19702 | Basic | 0603 |  |  | Capacitor_SMD:C_0603_1608Metric
U4 | BMI270 | 6-axis IMU | BMI270 | Bosch | C2836813 | Extended | LGA-14 |  |  | BMI270:BMI270_BOS
C16,C17 | 100nF | 0402, X7R, 16V, ±10% | CL05B104KO5NNNC | Samsung | C1525 | Basic | 0402 |  |  | Capacitor_SMD:C_0402_1005Metric
U5 | BME280 | Environmental sensor (T/P/H) | BME280 | Bosch | C92489 | Extended | LGA-8 2.5x2.5mm |  |  | Package_LGA:Bosch_LGA-8_2.5x2.5mm_P0.65mm_ClockwisePinNumbering | SDO tied to GND for I2C addr 0x76
R10,R11 | 4.7kΩ | 0402, 1% | 0402WGF4701TCE | Uni-Royal | C25900 | Basic | 0402 | 3286031 |  | Resistor_SMD:R_0402_1005Metric | I2C1 pullups
C18,C19 | 100nF | 0402, X7R, 16V, ±10% | CL05B104KO5NNNC | Samsung | C1525 | Basic | 0402 |  |  | Capacitor_SMD:C_0402_1005Metric
U6 | TCAN334GDR | CAN FD transceiver, 3.3V logic, 5 Mbps | TCAN334GDR | Texas Instruments | C189939 | Extended | SOIC-8 | 451 | 1.51 | Package_SO:SOIC-8_3.9x4.9mm_P1.27mm
R12,R13 | 0Ω | 0402, 1% (jumper) | 0402WGF0000TCE | Uni-Royal | C17168 | Basic | 0402 |  |  | Resistor_SMD:R_0402_1005Metric
C20 | 100nF | 0402, X7R, 16V, ±10% | CL05B104KO5NNNC | Samsung | C1525 | Basic | 0402 |  |  | Capacitor_SMD:C_0402_1005Metric
C21 | 1µF | 0603, X5R, 50V, ±10% | CL10A105KB8NNNC | Samsung | C15849 | Basic | 0603 |  |  | Capacitor_SMD:C_0603_1608Metric
D2 | PESD2CANFD27V-TR | CAN bus ESD/TVS | PESD2CANFD27V-TR | Nexperia | C552488 | Extended | SOT-23 |  |  | PESD2CANFD27V-TR:SOT23_PESD2_NEX
R14 | 120Ω | 0603, 1%, 100mW | 0603WAF1200T5E | Uni-Royal | C22787 | Basic | 0603 | 1771326 |  | Resistor_SMD:R_0603_1608Metric | CAN termination
J3 | Screw_Terminal_01x03 | 3-pin 3.5mm pluggable header (board side) | DB2EVC-3.5-3P-GN | DORABO | C430550 | Extended | 3P 3.5mm | 9225 |  | Connector_Phoenix_MC:PhoenixContact_MC_1 | 5_3-G-3.5_1x03_P3.50mm_Horizontal | Verify body outline silkscreen at PCB layout
J4 | Conn_01x02 | 2-pin 2.54mm header | HX PZ2.54-1x2P TP-YQ | hanxia | C41417359 | Extended | 1x2 2.54mm | 4719 | 0.01 | Connector_PinHeader_2.54mm:PinHeader_1x02_P2.54mm_Vertical | BOOT0 jumper
D3 | LED red | 0603, Vf 1.8-2.4V | KT-0603R | Hubei Kento | C2286 | Basic | 0603 | 7918661 | 0.01 | LED_SMD:LED_0603_1608Metric
D4 | LED amber | 0603, Vf 2.4V | KT-0603Y | Hubei Kento | C2287 | Extended | 0603 | 19755 | 0.01 | LED_SMD:LED_0603_1608Metric | Originally spec'd green; swapped to amber for 330Ω compatibility
D5 | LED yellow-green | 0603, Vf 2.0-2.2V | KT-0603YG | Hubei Kento | C2289 | Extended | 0603 | 48870 | 0.01 | LED_SMD:LED_0603_1608Metric
D6 | LED amber | 0603, Vf 2.4V | KT-0603Y | Hubei Kento | C2287 | Extended | 0603 | 19755 | 0.01 | LED_SMD:LED_0603_1608Metric | Duplicate of D4; distinguish by silkscreen + firmware blink pattern
R15-R18 | 330Ω | 0402, 1% | 0402WGF3300TCE | Uni-Royal | C25104 | Basic | 0402 | 3378192 |  | Resistor_SMD:R_0402_1005Metric | LED current limiting
SW2 | SW_Push | User button | HX 3x4x2-2P-1.6N | hanxia | C49234124 | Extended | SMD 3x4mm 2-pin | 101172 | 0.01 | Button_Switch_SMD:SW_SPST_TL3342 | Same part as SW1
C22 | 100nF | 0402, X7R, 16V, ±10% | CL05B104KO5NNNC | Samsung | C1525 | Basic | 0402 |  |  | Capacitor_SMD:C_0402_1005Metric
J5 | Conn_02x05_Odd_Even | SWD header 10-pin 1.27mm 2x5 SMD | KH-1.27PH180-2X5P-L7.2-S | Shenzhen Kinghelm | C4943297 | Extended | 2x5 1.27mm SMD | 2171 |  | Connector_PinHeader_1.27mm:PinHeader_2x05_P1.27mm_Vertical_SMD | ARM Cortex 10-pin Debug pinout
J6 | Conn_01x04 | UART header 4-pin 2.54mm | HX PZ2.54-1x4P TP-YQ | hanxia | C41417361 | Extended | 1x4 2.54mm | 13668 | 0.01 | Connector_PinHeader_2.54mm:PinHeader_1x04_P2.54mm_Vertical

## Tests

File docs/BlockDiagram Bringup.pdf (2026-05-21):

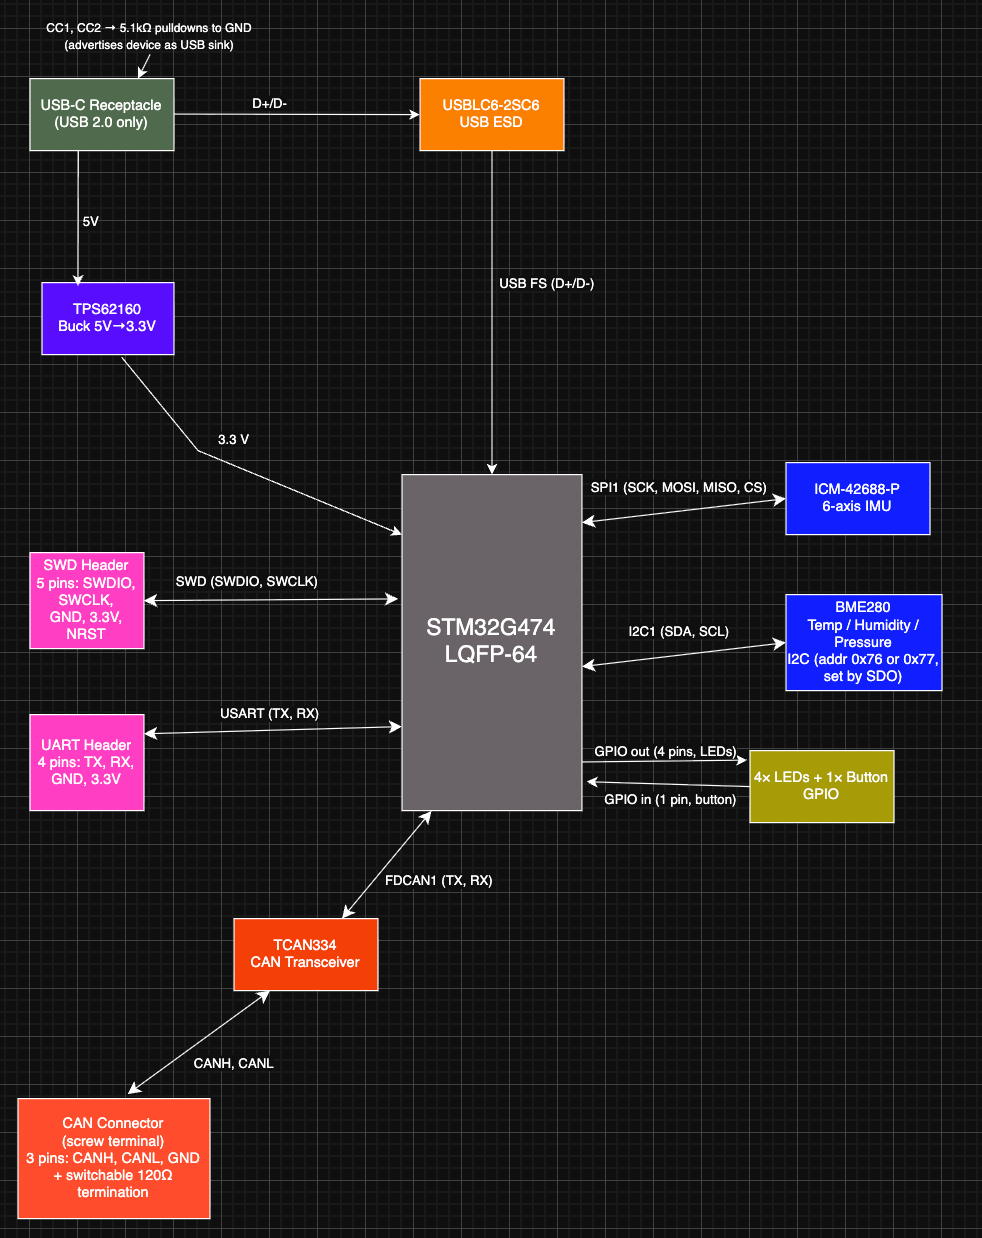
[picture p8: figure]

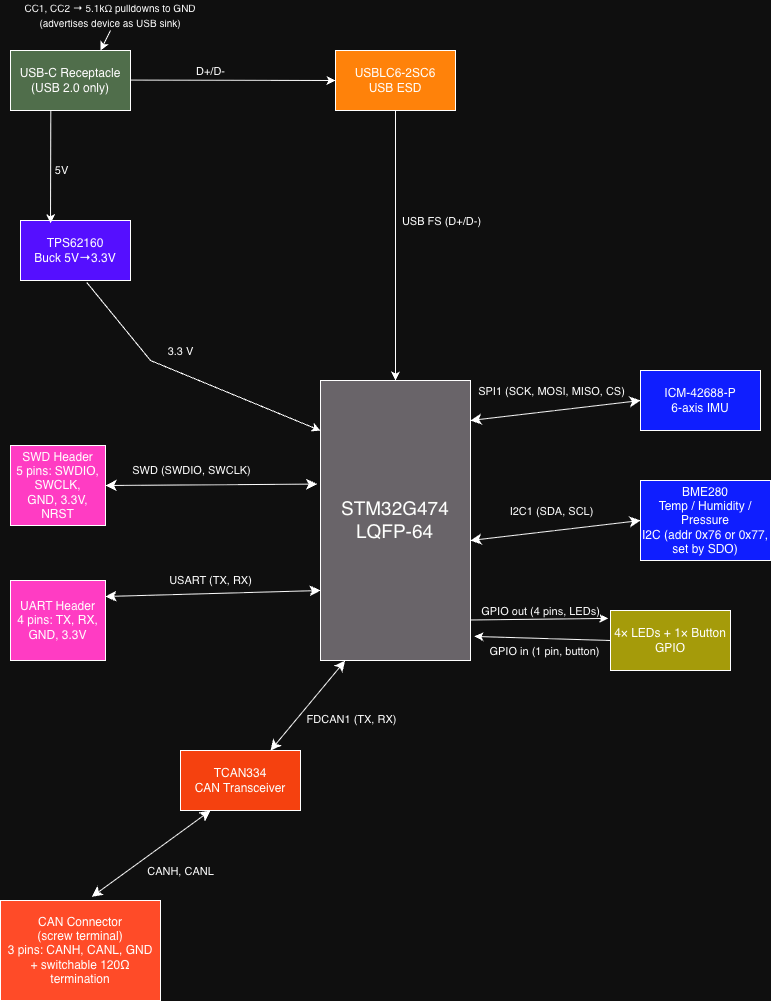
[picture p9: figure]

CANaryNode Block Diagram — Full Layout

Canvas organization:

- Left band: external connectors and inputs
- Middle band: the STM32G474 MCU (hub)
- Right band: sensors and outputs
- Power flows top-to-bottom on the left side; signals flow left-to-right into the MCU

Power ection (top-left, flowing down)

USB-C Receptacle (top-left corner) Outputs going down/right:

- VBUS (5V) → down to buck converter
- D+ / D- → right through USBLC6 → into MCU USB pins
- CC1, CC2 → each has a 5.1kΩ pulldown to GND (advertises "I'm a USB device, give me 5V")
- GND, Shield

TPS62160 Buck Converter (below USB-C)

- Input: 5V from USB VBUS
- Output: 3.3V rail that feeds everything — MCU, both sensors, transceiver
- This is your main power rail

Power rail color convention on the diagram:

- Red lines/labels = 5V
- Orange lines/labels = 3.3V
- Black/gray = GND
- Blue = signal arrows

Protection / ESD (between USB-C and MCU)

USBLC6-2SC6

- Sits in the data path between USB-C connector and MCU USB pins
- Clamps ESD spikes on D+/D-
- 4 pins of interest: D+ in, D+ out, D- in, D- out (plus VCC, GND)

The MCU (center)

STM32G474 (LQFP package, TBD pin count) Label the following interfaces on the MCU block, arranged around its edges:

Left side of MCU (signals coming in from the left band):

- USB (D+/D-) — connects to USBLC6
- SWD (debug) — to SWD header
- UART (debug) — to UART header

Right side of MCU (signals going out to sensors):

- SPI1 → ICM-42688-P (IMU)
- I2C1 → BME280 (environmental)
- (Optional SPI2 or shared SPI1 with different CS → MAX31855 thermocouple)

Bottom of MCU:

- FDCAN1 (TX, RX) → TCAN334 transceiver
- GPIO × 4 → LEDs
- GPIO × 1 → user button

Sensors (right band)

ICM-42688-P (IMU, top-right)

- Connected to MCU via SPI: SCK, MOSI, MISO, CS (4 wires)
- 6-axis: 3-axis accel + 3-axis gyro
- Powered from 3.3V rail

BME280 (environmental, middle-right)

- Connected to MCU via I2C: SDA, SCL (2 wires)
- Temperature, humidity, pressure
- Powered from 3.3V rail
- I2C address: 0x76 or 0x77 (set by SDO pin)

MAX31855 (optional thermocouple amp, bottom-right — mark as optional)

- Connected to MCU via SPI (shares bus with IMU, separate CS pin)
- Reads K-type thermocouple for high temperatures

CAN section (bottom-middle)

TCAN334 CAN Transceiver

- MCU side (logic, 3.3V): TXD, RXD connect to MCU FDCAN1 pins
- Bus side (differential, ~2.5V common mode): CANH, CANL go out to connector
- Powered from 3.3V rail

CAN Connector (bottom-left corner — screw terminal or DB9)

- Pins: CANH, CANL, GND
- Switchable 120Ω termination resistor between CANH and CANL (jumper or DIP switch)

Debug + user interface (left band, below USB-C)

SWD Header (5 pins)

- SWDIO, SWCLK, GND, 3.3V, NRST
- This is how you flash and debug — connects to ST-Link

UART Header (4 pins)

- TX, RX, GND, 3.3V
- Backup debug channel, printf logging

LEDs × 4 (right of MCU or bottom)

- Each driven by a GPIO through a current-limiting resistor
- Conventional assignment: power LED (always on when 3.3V present), heartbeat (toggles in main loop), CAN activity, user/fault

Button × 1

- One side to GPIO, other side to GND (active-low)
- GPIO uses MCU internal pull-up

Recap of signal flow

A CAN message arrives → TCAN334 converts differential to logic → MCU FDCAN1 RX → firmware processes it.

A sensor reading happens → MCU SPI1 clocks data out of ICM-42688-P → firmware packages it → MCU FDCAN1 TX → TCAN334 drives differential bus → message goes out.

USB config: laptop sends command → USB-C → USBLC6 → MCU USB → firmware updates config struct → response back the same path.

Two small additions to file away:

- It's not just the MCU that needs 3.3V — both sensors and the CAN transceiver also run on 3.3V. The buck feeds the whole board.
- "Why a buck and not an LDO?" → efficiency. LDO burns the extra voltage as heat (~66% efficient), buck switches it (~90% efficient). Memorize that — it's a guaranteed interview question.

USB Data Path (D+/D-) and ESD Protection

D+ and D-

- The two data wires of USB. They carry data as a differential pair — D+ and D- always swing in opposite directions.
- Differential signaling rejects noise: any noise that hits both wires equally gets cancelled when the receiver looks at the difference between them.
- USB Full Speed (what the G474 supports) = 12 Mbps over this pair.
- Must be routed as a controlled-impedance 90Ω differential pair on the PCB (this is why the JLC04161H-7628 stackup was chosen).
- Trace length matching matters: D+ and D- should be the same length within a few mm so signals arrive simultaneously.

Why ESD protection is needed

- ESD = electrostatic discharge. Walking across carpet and touching a USB plug can dump ~8–15 kV into the connector for a microsecond.
- USB pins on the MCU are rated for maybe ±2 kV human-body-model. Direct ESD = dead MCU.
- The USB-C connector is the most exposed part of the board — fingers and cables touch it constantly. Highest ESD risk on the whole design.

What USBLC6-2SC6 does

- TVS diode array (Transient Voltage Suppressor).
- Sits across each data line to ground. Normally invisible (high impedance, low capacitance ~3.5 pF so it doesn't distort USB signals).
- When an ESD spike hits, the diode "snaps on" in nanoseconds and shunts the current to ground before it reaches the MCU.
- After the spike passes, it returns to high impedance. Self-resetting.
- Standard part on every USB 2.0 design — costs $0.08, prevents a dead MCU.

Why specifically the USBLC6-2SC6 and not something else

- Low capacitance (3.5 pF) — critical for high-speed signals. A cheap TVS with 20 pF capacitance would distort USB.
- 4-line variant: protects D+, D-, plus has integrated steering diodes to a single TVS element. Compact.
- IEC 61000-4-2 rated for ±15 kV air discharge — way more than ESD events in the real world.

Placement rule (matters in layout, not the block diagram yet)

- USBLC6 must be placed as close to the USB-C connector as possible — ideally within a few mm.
- ESD energy has to be shunted before it reaches anything fragile. If the ESD chip is on the MCU side of a 5cm trace, the trace itself is the antenna and the MCU still sees the spike.
- This is a "rules people violate and then wonder why their board dies" thing. Worth remembering.

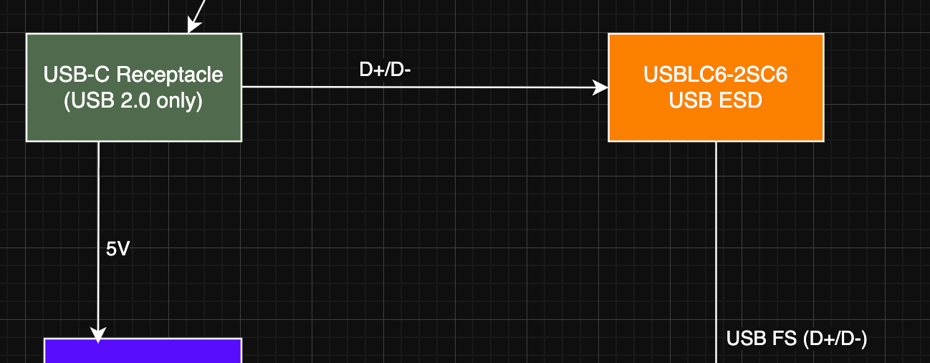
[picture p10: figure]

The problem USB-C solves: Old USB (A/B) had different connectors for hosts and devices. A laptop = host = supplies power. A phone = device = receives power. Connector shape told you which was which.

USB-C uses the same connector on both ends. So how does the laptop know "this is a device that wants power" vs "this is another laptop"?

The answer: CC pins. USB-C has two pins called CC1 and CC2 (Configuration Channel). They're how the two ends negotiate roles.

- A host (laptop) puts pull-up resistors on its CC pins (5.1kΩ to 5V)
- A device (your board) puts pull-down resistors on its CC pins (5.1kΩ to GND)

When you plug in, the laptop senses the voltage on the CC line. If it sees the pulldown, it thinks "ok, that's a device, I'll turn on 5V." If it sees nothing (no pulldown), it thinks "nothing's there" and keeps VBUS off.

Why 5.1kΩ specifically: The USB-C spec defines this exact value. The laptop measures the voltage divider formed by its pull-up and your pull-down. 5.1kΩ produces the voltage the spec expects for "standard device, draw up to 3A."

What you need to do: Two 5.1kΩ resistors on your board — one from CC1 to GND, one from CC2 to GND. Two resistors because the connector is reversible — whichever orientation you plug in, one of them becomes the active CC line.

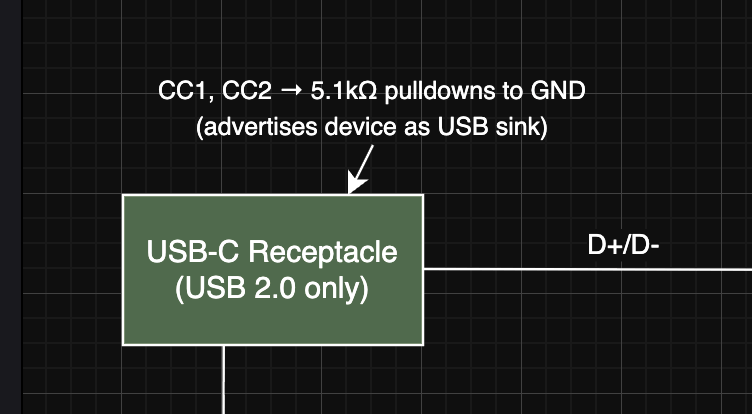
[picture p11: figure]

SPI = Serial Peripheral Interface. A 4-wire protocol for the MCU to talk to chips like sensors, flash memory, displays. Faster than I2C, simpler than USB.

The 4 wires:
SCK — Serial Clock. MCU generates a clock signal; every tick = one bit transferred. Whoever controls the clock controls the speed.
MOSI — Master Out, Slave In. Data from MCU → sensor. (Commands, register addresses, config.)
MISO — Master In, Slave Out. Data from sensor → MCU. (Sensor readings.)
CS — Chip Select. A "wake up, I'm talking to you" line. MCU pulls CS low to start a transaction, high to end it. Active-low.
Why CS exists: SPI lets multiple devices share SCK/MOSI/MISO. Each device gets its own CS line. Only the chip with CS pulled low listens; the rest ignore the bus. That's how you'd add the optional MAX31855 thermocouple later — same SPI bus, second CS pin.

SPI1: STM32G474 has multiple SPI peripherals (SPI1, SPI2, SPI3, SPI4). "SPI1" just names which hardware peripheral you're using. The choice affects which physical pins and which DMA channels — that's a CubeMX decision later.

A transaction looks like:
MCU pulls CS low
MCU clocks out a register address on MOSI while reading garbage on MISO MCU clocks dummy bytes on MOSI while reading sensor data on MISO MCU pulls CS high

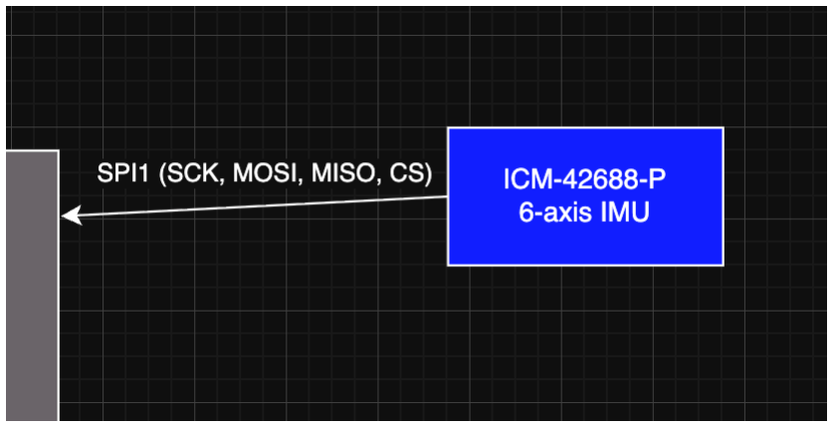
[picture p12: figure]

I2C = Inter-Integrated Circuit. A 2-wire protocol for short-distance, low-speed chip-to-chip communication.

The 2 wires:
SDA — Serial Data. Bidirectional, carries both addresses and data.
SCL — Serial Clock. MCU generates the clock.

Key differences from SPI:
2 wires vs 4 — much less PCB space, simpler routing.
No chip select. Instead, every device has a unique 7-bit address baked into the chip. MCU sends the address on the bus; only the matching device responds. BME280 = 0x76 or 0x77 depending on how its SDO pin is wired.
Multi-drop. You can hang many devices on the same 2 wires — they all share SDA and SCL. Add another I2C sensor later? Just connect it to the same lines.
Slower. Standard mode = 100 kHz, Fast mode = 400 kHz, Fast-mode Plus = 1 MHz. SPI runs at 10+ MHz easily.
Needs pull-up resistors on SDA and SCL (typically 4.7kΩ to 3.3V). The bus is "open-drain" — devices can only pull the lines low; the resistors pull them high when nobody's talking. Without pull-ups, I2C doesn't work. Common beginner mistake.

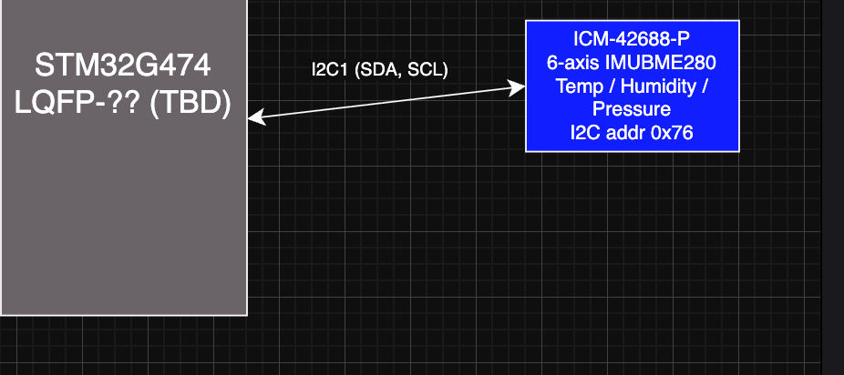
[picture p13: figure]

CAN Section Notes

CAN bus (general)

- 2-wire differential bus: CANH and CANL
- Used in cars, drones, satellites, industrial robots — Anduril, SpaceX, Tesla all use it
- Multi-drop: many nodes share the same 2 wires, each with a unique message ID
- Robust against electrical noise (differential signaling, like USB D+/D-)
- Speeds: classic CAN up to 1 Mbps, CAN FD ("Flexible Data-rate") up to 5–8 Mbps

TCAN334 (the transceiver)

- Translates between MCU logic (3.3V single-ended) and CAN bus (differential ~2.5V common mode)
- MCU side: TX (out), RX (in) — connects to MCU's FDCAN1 peripheral
- Bus side: CANH, CANL — go out to the connector
- Has built-in ESD protection on the bus pins (CAN connectors are external = ESD-exposed, same logic as USB)
- Powered from 3.3V rail

CAN Connector

- 3 pins: CANH, CANL, GND
- Screw terminal (or DB9) — easy to wire field connections to other CAN nodes
- GND is required as a common reference between nodes

120Ω termination (switchable)

- CAN buses need a 120Ω resistor at each end of the bus to absorb signal reflections

- Without termination, signals bounce back and corrupt data — classic transmission-line problem
- A node in the middle of the bus does NOT terminate (would create wrong impedance)
- A node at an end of the bus DOES terminate
- Your board doesn't know where it'll be on the bus, so make termination switchable (jumper or DIP switch) — user chooses based on physical location

FDCAN1 (the MCU peripheral)

- The G474 has two FDCAN controllers (FDCAN1, FDCAN2). Using FDCAN1.
- "FD" = Flexible Data-rate — supports both classic CAN and the faster CAN FD variant
- Generates the bit timing, handles framing, error detection, arbitration

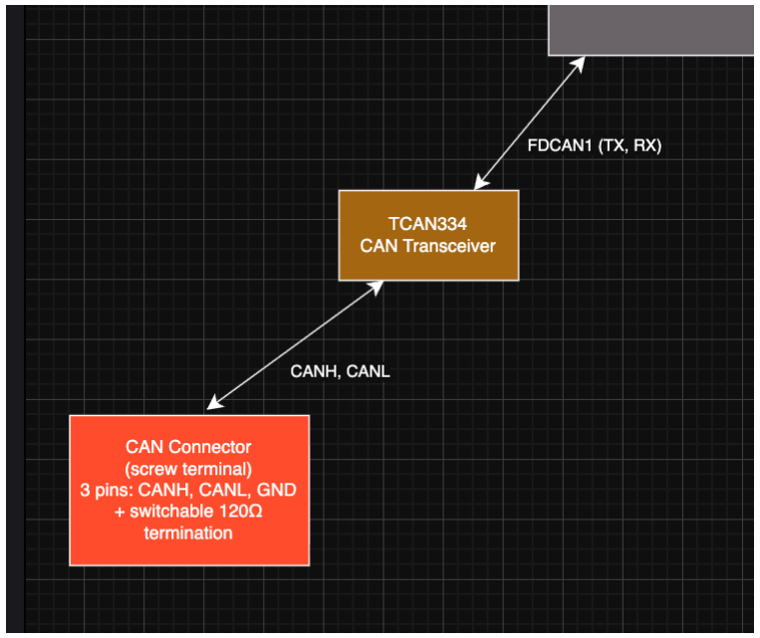
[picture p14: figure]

SWD (Serial Wire Debug)
ARM standard for programming and debugging Cortex-M chips

### 2 signal pins: SWDIO (bidirectional data), SWCLK (clock)

Plus GND, 3.3V (powers the debugger), NRST (reset)
You plug an ST-Link or J-Link debugger into this header to flash firmware and step through code Without this header you can't program the board

How it works in practice:
You build your firmware on your laptop → produces a .elf or .bin file
You plug an ST-Link debugger (~$10 clone, or a Nucleo board can act as one) into the SWD header

The other end of the ST-Link plugs into your laptop via USB
Software on your laptop (OpenOCD, STM32CubeProgrammer) talks through the ST-Link → through the SWD pins → into the MCU's debug core
Firmware gets written to flash. Done.

What "debug" means here, beyond flashing:
Breakpoints — pause execution at a specific line of code Step through code one line at a time
Inspect variables in RAM while the chip is running Read/write registers directly to test peripherals
Halt and resume the CPU
Watch live variables update as the code runs

All of this happens through those same 2 signal wires (SWDIO + SWCLK) — they're a bidirectional debug protocol, not just "programming."
Why each pin on the header:

SWDIO — bidirectional data
SWCLK — clock from debugger
GND — common reference
3.3V — lets the debugger sense your board's voltage level (so it talks at the right logic level) NRST — lets the debugger force-reset the MCU if firmware crashes

Without SWD, you can't develop. USB DFU is a fallback for flashing only, not debugging. Real embedded work means SWD.

UART (Universal Asynchronous Receiver/Transmitter)
Old-school serial port — TX, RX, GND
Used for printf-style debug logging when USB isn't working yet
Connect to a USB-to-UART dongle (~$5) → see logs in any terminal program
Backup channel: if USB enumeration breaks or the bootloader hangs, UART still works

Purpose: print debug messages from the MCU to your laptop.

When code runs on a microcontroller, you can't print("got here") and see it on a screen — the MCU has no screen. You need a way to send text out so you can see what your code is doing. UART is the simplest way.

How it works in practice:

1. In your firmware, you initialize the UART peripheral (set baud rate, e.g. 115200)
2. You call printf("temperature = %d\n", temp) — firmware HAL routes that through the UART TX pin
3. UART pin sends bits at 115200 baud → through the header → into a USB-to-UART dongle (FTDI, CP2102, ~$5)

4. The dongle shows up on your laptop as a COM port (Windows) or /dev/ttyUSB0 (Linux/Mac)
5. You open a terminal program (PuTTY, minicom, screen) → see the text scroll by in real time

Why you need this when SWD already exists:

- SWD debugging is invasive — when you set a breakpoint, you halt the CPU. Some bugs only happen at full speed (timing, ISRs, real-time stuff). Halting changes the behavior, so you can't catch them.
- UART is non-invasive — the MCU keeps running, just spits out text. Perfect for "what's happening during this 50 ms window."
- UART works without a debugger plugged in. Useful for field debugging when the board is deployed.
- UART is your fallback when something is fundamentally broken — e.g., the USB stack didn't enumerate, or the firmware is hung in a fault handler. UART can be made to work from literally the first instruction of main().

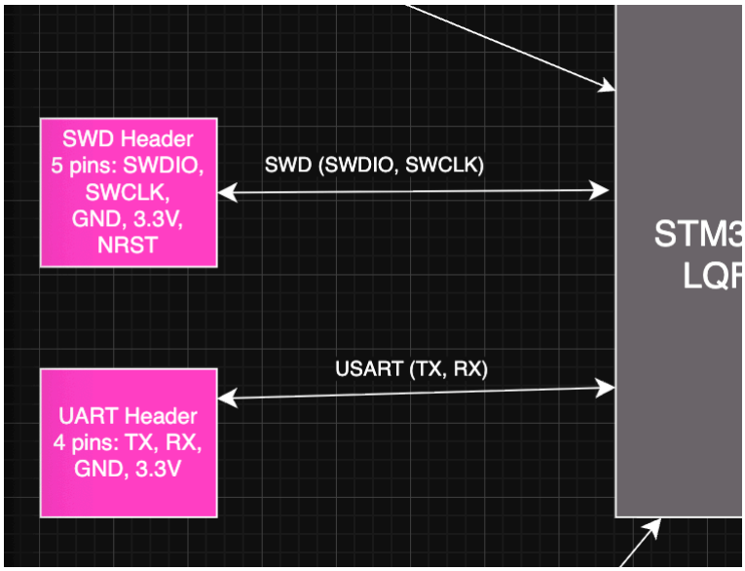
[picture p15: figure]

GPIO (General-Purpose Input/Output)

Generic digital pins on the MCU. Software controls whether each pin is an input or output. Output mode: firmware writes 1 or 0 → pin drives 3.3V or 0V. Used for LEDs, enabling chips, chip-select lines.
Input mode: firmware reads the pin → returns 1 if voltage is high, 0 if low. Used for buttons, switches, status lines from other chips.
Open-drain vs push-pull: push-pull actively drives both high and low (normal output). Open-drain only pulls low; needs an external pull-up to go high (used for I2C, shared signals). Internal pull-up/pull-down: every STM32 GPIO has optional internal resistors (~40kΩ) you enable in firmware. Saves you from soldering an external resistor for a button.
Alternate function: the same physical pin can be repurposed as SPI clock, UART TX, timer output, etc. CubeMX shows you the alternate-function table — that's the pin-planning step. Interrupts: a GPIO input can trigger an interrupt on rising/falling edge. Used for "wake me up when the button is pressed" without polling.
For your board: 4 pins as push-pull outputs (LEDs), 1 pin as input with internal pull-up (button). Total 5 GPIO

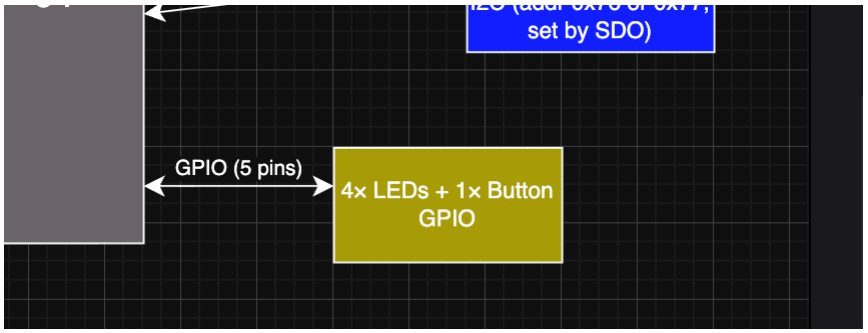
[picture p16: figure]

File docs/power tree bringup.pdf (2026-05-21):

## CANaryNode Power Tree

What this document is: A map of every voltage rail on the board, what creates it, what consumes it, and how much current each load draws. Used to verify that the chosen regulator is correctly sized, decoupling is adequate, and trace widths are sufficient.

Design summary: The board has two rails. USB-C VBUS supplies 5V from the host (up to 3A per USB 2.0 spec). That 5V feeds the TPS62160 buck converter, which steps it down to 3.3V at up to 1A. Everything else on the board — MCU, both sensors, CAN transceiver, LEDs — runs from that single 3.3V rail. The 5V rail is a pass-through with no other loads.

A buck converter was chosen over an LDO for efficiency (~90% vs ~66%). At expected loads this difference is small in absolute terms but demonstrates correct power-supply selection for portfolio purposes and scales cleanly if future revisions add higher-current peripherals.

What's on the power tree (current-drawing chips):

1. STM32G474
2. ICM-42688-P
3. BME280
4. TCAN334
5. (LEDs — not a chip but draws current)

What's NOT on the power tree, but IS going on the PCB:

- USBLC6-2SC6 ESD chip — passive TVS diode, draws essentially zero current in normal operation (only conducts during ESD events). Not a load.
- TPS62160 buck converter — this is the source of the 3.3V rail, not a load on it. Its own quiescent current is ~17 µA, negligible.
- All passives — resistors, capacitors, inductor. They don't have a "supply current" the way active chips do. Their current is determined by the circuit they're in (e.g., LED resistor current is already counted in the LED row).
- Pull-up resistors on I2C (4.7 kΩ): each pulls ~700 µA when the bus is low. Tiny but not zero — we'll handle as part of MCU GPIO budget.
- Connectors — USB-C, CAN screw terminal, SWD/UART headers. Mechanical only, no current.
- LEDs — they draw current but aren't "chips" per se. Counted as a row already.
- Button — passive switch, no current draw except briefly when pressed.

** For ‘load name’ we are using the operating mode of the chip which would draw the worst case current.

STM32G474 active — CPU in Run mode at 170 MHz with USB, FDCAN, SPI, I2C, USART all enabled. Worst-case ongoing current.
ICM-42688-P normal — Accelerometer + gyroscope both on in Low Noise mode. Continuous 6-axis sampling.
BME280 forced mode — Take one measurement on command, return to sleep. The mode used for slow-changing environmental data; current dominated by brief measurement spikes. TCAN334 active — Normal mode, actively driving the bus (dominant/TX state). Higher than receive-only current.
LEDs (4× @ ~5mA all on) — Worst case where all 4 status LEDs are lit simultaneously. 5mA per LED is a design choice (bright enough to see, low enough to ignore in power budget).
- "Typical" = current in the mode you expect during normal operation
- "Max" = current in the highest-power mode the chip supports
Load | Typical (mA) | Max (mA) | Source/Datasheet Section
STM32G474 active @170 MHz | 29.5 | 42.0 | DS12288 §5.3.5, Table 21, 170 MHz row
ICM-42688-P normal Low-Noise Mode, 6-Axis Gyroscope + Accelerometer | 0.88 | 1.5(est) | DS-000347 §3.3.1, Table 3, 6-axis LN
BME280 forced mode: 714 µA (I_DDP, current during pressure measurement) | 0.71 | 1.0(est) | BST-BME280-DS002 §1.1, Table 1, I_DDP peak
TCAN334 active Dominant, High Bus Load | 15.0(est) | 60.0 | SLLSEU4 §5.5, I_CC Normal Mode
LEDs (4× @ ~5mA all on) | 5.0 (1.0 on avg) | 20.0 | Design choice
**Subtotal** | 51.1 | 124.5 | –
**+ 50% headroom** | – | 186.8 | –
**TPS62160 rating** | – | 1000 | –

**TPS62160(Buck Converter) Rating" explained

- EVERYTHING on the board is connected to the 3.3V rail (for CANary node), the buck needs to be able to provide all the current everything is pulling. The buck provides 1000mA we are only using ~187mA at most.

I picked a 1A buck for a 200 mA load on purpose. It runs cooler, leaves room to add features later, handles sudden current spikes better, and the cheaper alternative only saves 50 cents — not worth the tradeoff.

The rating is the regulator's maximum output current — how much it can deliver before it fails or shuts down. For the TPS62160 it's 1000 mA (1 A) per its datasheet.

You compare your headroomed worst case against this number:

186.8 mA needed vs 1000 mA available = 18.7% utilization

You're using less than a fifth of what the regulator can deliver. Massive headroom.

Note for power-tree doc — STM32G474 current sourcing

Table used: Table 21 — "Current consumption in Run and Low-power run modes, code with data processing running from Flash in single Bank, ART enable (Cache ON Prefetch OFF)" (DS12288, §5.3.5)

Why this table out of the ~14 current-consumption tables:

- Run mode (not Low-power run): worst-case sizing — assume CPU is always at full clock
- Code from Flash, single bank: the default execution configuration. Dual-bank is only enabled for A/B firmware update schemes (relevant to Project 2 bootloader, not CANaryNode)
- ART enable, Cache ON Prefetch OFF: ST's standard "typical use" condition — most realistic for everyday firmware
- Sleep/Stop/Standby tables ignored — those are for low-power analysis, not regulator sizing

Row picked: f_HCLK = 170 MHz (max clock for G474), all peripherals enabled. This is the worst-case ongoing current the firmware will demand from the 3.3V rail.

Currents read at Typ = 25°C, Max = 85°C. Selected 85°C as the upper bound for typical indoor/lab operation. If CANaryNode were deployed in a vehicle or outdoor environment, the 125°C column would be more appropriate.

—----------------------------------------------------------------------------------------------------------------------------

## Note for power-tree doc — ICM-42688-P current sourcing

Table used: Table 3 — D.C. Electrical Characteristics (DS-000347, §3.3.1)

Row picked: Low-Noise Mode, 6-Axis Gyroscope + Accelerometer = 0.88 mA typical at 25°C. This is the worst-case ongoing current — both sensors active in highest-performance mode.

Caveats captured:
Datasheet characterized at VDD = 1.8 V. CANaryNode runs the chip at 3.3 V, so actual current may be 10–20% higher. Will measure during bring-up.
Datasheet provides Typ only, no Max column. Used 1.5 mA as estimated Max for sizing headroom.

Filed away for schematic time (not power-related):
I²C address from §3.3.2 Table 4: 0x68 (AP_AD0 = 0) or 0x69 (AP_AD0 = 1). Pin-strap choice during schematic capture.
VDDIO and VDD can be separate rails (chip supports split supplies). We'll tie both to 3.3V for simplicity.
Spec'd operating range: -40°C to +85°C — fine for indoor/lab use. —----------------------------------------------------------------------------------------------------------------------------

Note for power-tree doc — BME280 current sourcing

Table used: Table 1 — Electrical parameter specification (BST-BME280-DS002 §1.1)

Number picked: 714 µA (I_DDP, current during pressure measurement) — the highest single-measurement current in the table.

Reasoning:

- BME280 measures temperature, humidity, and pressure sequentially, not simultaneously. Peak current = highest single measurement, not the sum.
- Pressure measurement is the worst case at 714 µA. Humidity is 340 µA, temperature is 350 µA.
- In forced mode, the chip is in standby (0.2 µA) most of the time and only spikes to 714 µA briefly per measurement. Average current is much lower than peak, but the regulator must handle peak instantaneous demand → power tree uses peak.

Caveats captured:

- Datasheet characterized at VDD = 1.8 V. CANaryNode runs the chip at 3.3 V — actual current may be slightly higher.
- Datasheet provides Typ only for measurement currents. Max value (1.0 mA) estimated for headroom.

## Note for power-tree doc — TCAN334 current sourcing

Table used: Electrical Characteristics, I_CC row (TCAN334 datasheet SLLSEU4, §5.5)

Numbers picked:

Max: 60 mA — Dominant state, High Bus Load (50Ω). Represents a properly terminated CAN bus (two 120Ω resistors in parallel = 60Ω, close enough). Worst case for active transmission. Typical: 15 mA (est.) — datasheet shows Recessive state at only 3.5 mA. The bus sits recessive most of the time (idle or transmitting 1-bits), with brief dominant pulses during TX. Estimated average between recessive (3.5 mA) and dominant (60 mA) bursts.
Notes:

TCAN334 datasheet characterized at VCC = 3.3 V — no voltage conversion caveat (unlike the BME280 and IMU).
180 mA "Dominant with bus fault" row ignored — fault condition (CANH shorted to -12V), not normal operation. Buck's overcurrent protection handles this.

## Note for power-tree doc — LEDs

Source: Design choice, not datasheet.

Numbers picked:
Max: 20 mA — 4 LEDs × 5 mA each, all on simultaneously. Worst case where firmware lights every status LED at once.
Typical: 5 mA — assumes one LED on at a time on average (e.g., heartbeat blinking, power-on LED steady, others off).
Sizing reasoning:
5 mA per LED is the design target. Bright enough to see in normal indoor lighting, low enough that 4 of them combined is negligible against the rail budget.
Current set by series resistor: R = (V_rail - V_F) / I_LED = (3.3 - ~2.0) / 0.005 ≈ 260 Ω. Will use standard 330 Ω → ~3.9 mA actual (slightly conservative, fine).
V_F depends on LED color: red/yellow ≈ 2.0 V, green ≈ 2.2 V, blue/white ≈ 3.0 V. Will pick during schematic capture.

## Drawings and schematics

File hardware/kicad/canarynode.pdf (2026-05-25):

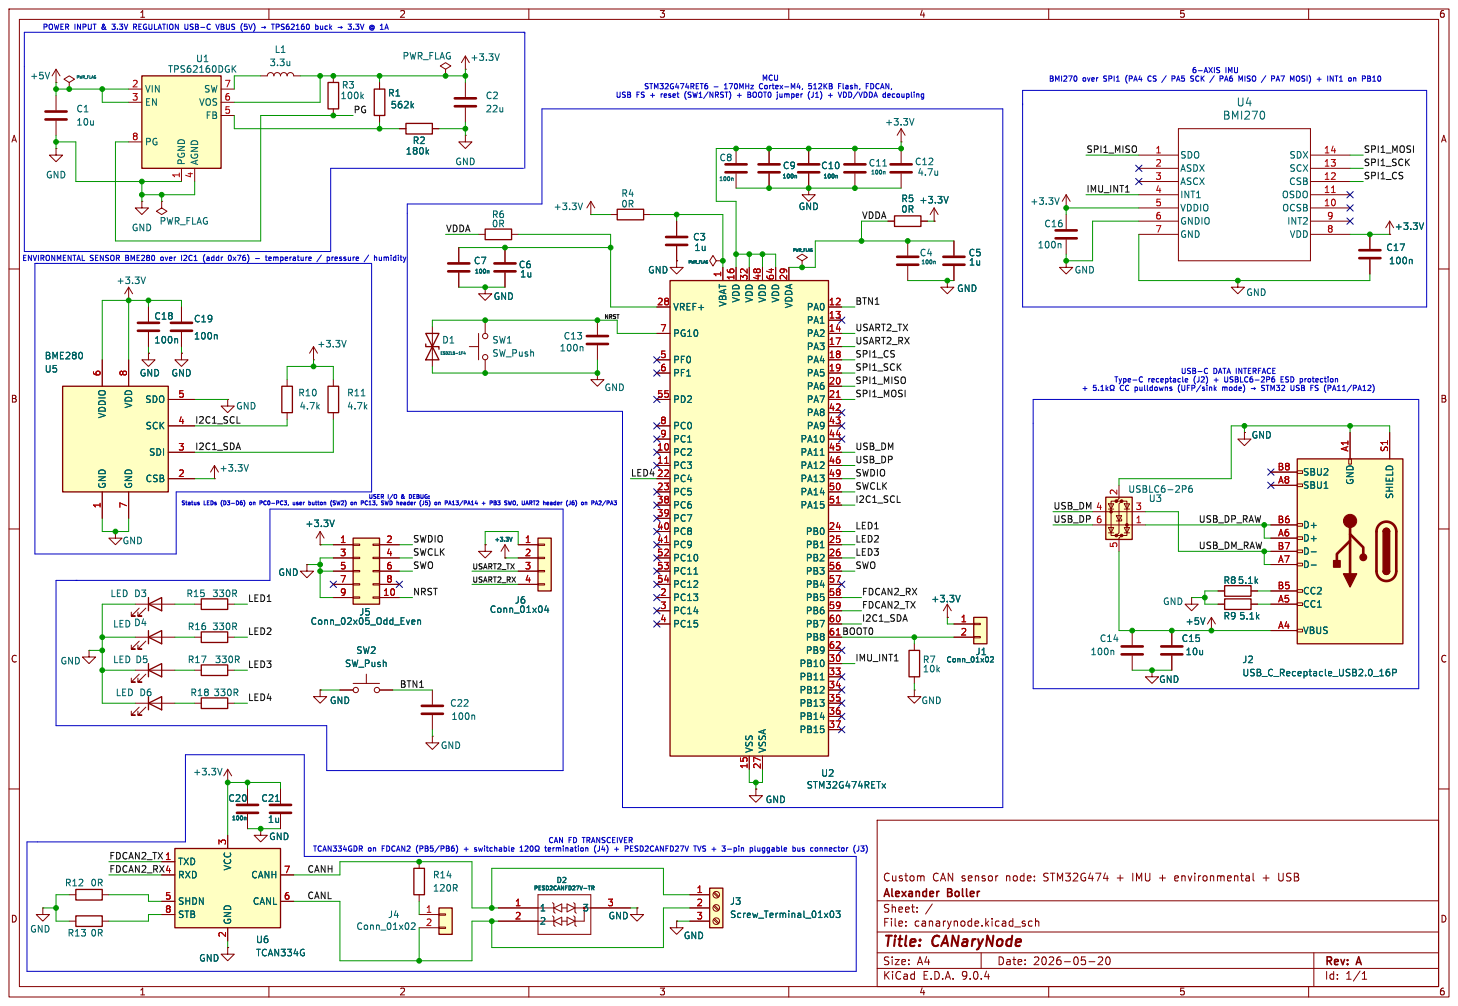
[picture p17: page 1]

4 SW 7 VOS 6 FB 5 U1 TPS62160DGK GND
3.3u VDDIO

BMI270 over SPI1 (PA4 CS / PA5 SCK / PA6 MISO / PA7 MOSI) + INT1 on PB10

1 VDD 16 VDD 32 VSS 15 VDD 48 VSSA 27 VDD 64 VDDA 29 PA0 12 PA1 13 PA2 14 PA3 17 PA4 18 PA5 19 PA6 20 PA7 21 PA8 42 PA9 43 PA10 44 PA11 45 PA12 46 PA13 49 PA14 50 PA15 51 PB0 24 PB1 25 PB2 26 PB3 56 PB4 57 PB5 58 PB6 59 PB7 60 PB8 61 PB9 62 PB10 30 PB11 33 PB12 34 PB13 35 PB14 36 PB15 37 U2 STM32G474RETx R15 330R

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

7 SDO 5 SCK 4 SDI 3 CSB 2 U5BME280

7 SDO 5 SCK 4 SDI 3 CSB 2 GND

2 CANH 7 CANL 6 GND GND

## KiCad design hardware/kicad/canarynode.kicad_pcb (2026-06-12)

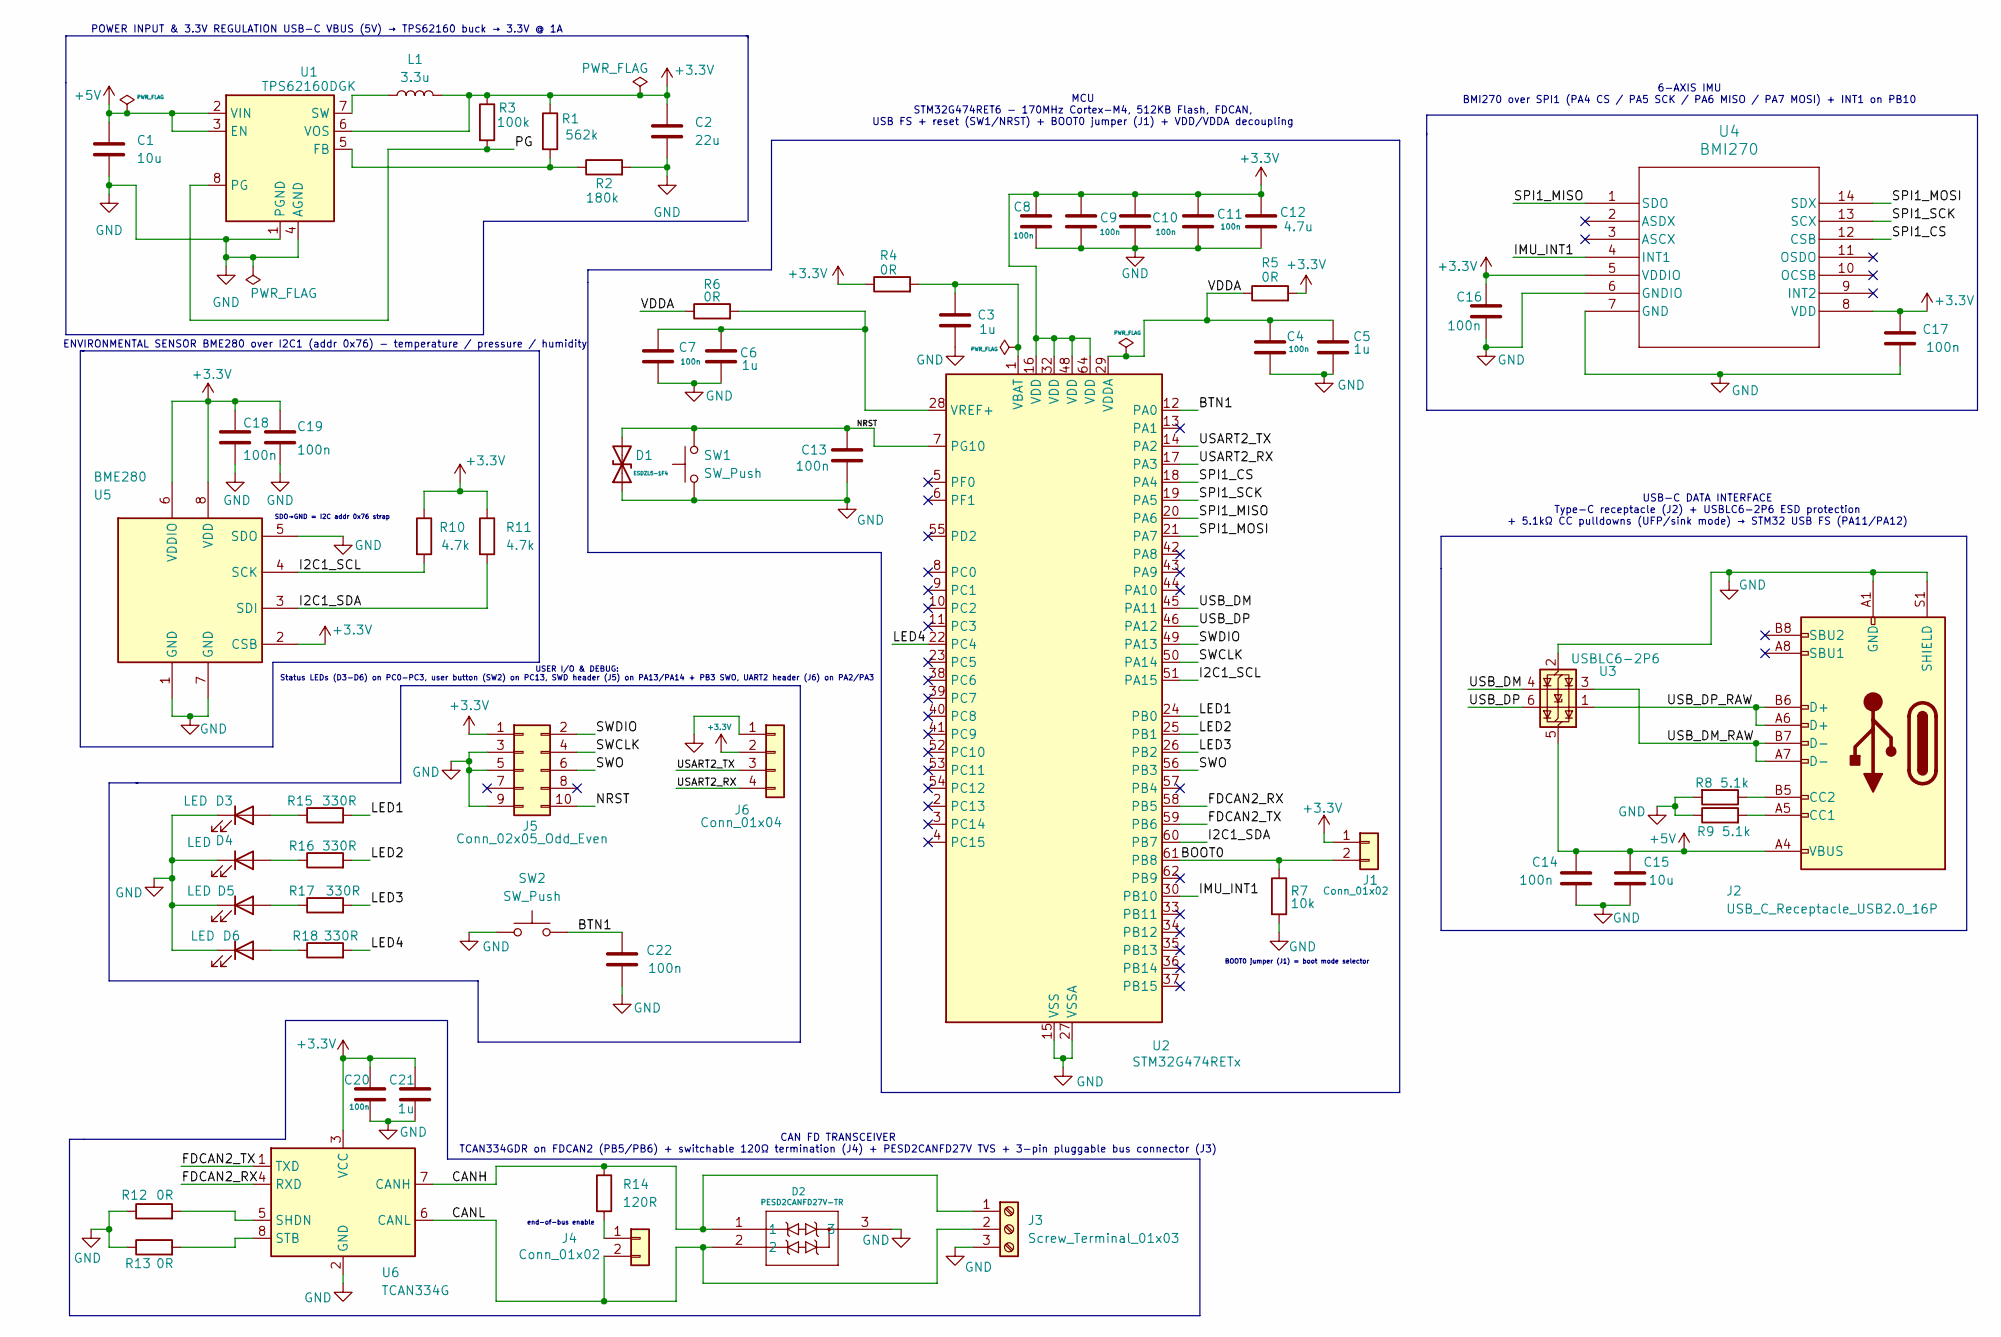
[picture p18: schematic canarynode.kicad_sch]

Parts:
C1, C15: 10u; C_0603_1608Metric; LCSC C19702
C2: 22u; C_0603_1608Metric; LCSC C59461
C3, C5, C6, C21: 1u; C_0603_1608Metric; LCSC C15849
C4, C7, C8, C9, C10, C11, C13, C14, C16, C17, C18, C19, C20, C22: 100n; C_0402_1005Metric; LCSC C1525
C12: 4.7u; C_0603_1608Metric; LCSC C19666
D1: ESDZL5-1F4; D_0201_0603Metric; LCSC C2970171
D2: PESD2CANFD27V-TR; SOT23_PESD2_NEX; LCSC C552488
D3: LED; LED_0603_1608Metric; LCSC C2286
D4, D6: LED; LED_0603_1608Metric; LCSC C2287
D5: LED; LED_0603_1608Metric; LCSC C2289
J1, J4: Conn_01x02; PinHeader_1x02_P2.54mm_Vertical; LCSC C41417359
J2: USB_C_Receptacle_USB2.0_16P; USB_C_Receptacle_HRO_TYPE-C-31-M-12; LCSC C165948
J3: Screw_Terminal_01x03; PhoenixMC_1x03_P3.5_DB2EVC.kicad_mod; LCSC C430550
J5: Conn_02x05_Odd_Even; PinHeader_2x05_P1.27mm_Vertical_SMD; LCSC C4943297
J6: Conn_01x04; PinHeader_1x04_P2.54mm_Vertical; LCSC C41417361
L1: 3.3u; IND_XFL3012_COC; LCSC C3911580
R1: 562k; R_0402_1005Metric; LCSC C48838
R2: 180k; R_0402_1005Metric; LCSC C25760
R3: 100k; R_0402_1005Metric; LCSC C25741
R4, R5, R6, R12, R13: 0R; R_0402_1005Metric; LCSC C17168
R7: 10k; R_0402_1005Metric; LCSC C25744
R8, R9: 5.1k; R_0402_1005Metric; LCSC C25905
R10, R11: 4.7k; R_0402_1005Metric; LCSC C25900
R14: 120R; R_0603_1608Metric; LCSC C22787
R15, R16, R17, R18: 330R; R_0402_1005Metric; LCSC C25104
SW1, SW2: SW_Push; SW_SPST_PTS645Sx43SMTR92; LCSC C6630024
U1: TPS62160DGK; MSOP-8_3x3mm_P0.65mm; LCSC C60726
U2: STM32G474RETx; LQFP-64_10x10mm_P0.5mm; LCSC C521608
U3: USBLC6-2P6; SOT-666; LCSC C15999
U4: BMI270; BMI270_BOS; LCSC C2836813
U5: BME280; Bosch_LGA-8_2.5x2.5mm_P0.65mm_ClockwisePinNumbering; LCSC C92489
U6: TCAN334G; SOIC-8_3.9x4.9mm_P1.27mm; LCSC C189939

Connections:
+3.3V: C2.1, C8.1, C9.1, C10.1, C11.1, C12.1, C16.1, C17.1, C18.1, C19.1, C20.1, C21.1, J1.1, J5.1, J6.2, L1.2, R1.1, R3.1, R4.1, R5.2, R10.1, R11.1, U1.6 (VOS), U2.16 (VDD), U2.32 (VDD), U2.48 (VDD), U2.64 (VDD), U4.5 (VDDIO), U4.8 (VDD), U5.2 (CSB), U5.6 (VDDIO), U5.8 (VDD), U6.3 (VCC)
+5V: C1.1, C14.1, C15.1, J2.A4 (VBUS), J2.A9 (VBUS), J2.B4 (VBUS), J2.B9 (VBUS), U1.2 (VIN), U1.3 (EN), U3.5 (VBUS)
/BOOT0: J1.2, R7.1, U2.61 (PB8)
/BTN1: C22.1, SW2.2, U2.12 (PA0)
/CANH: D2.1, J3.1, R14.1, U6.7 (CANH)
/CANL: D2.2, J3.2, J4.2, U6.6 (CANL)
/FDCAN2_RX: U2.58 (PB5), U6.4 (RXD)
/FDCAN2_TX: U2.59 (PB6), U6.1 (TXD)
/I2C1_SCL: R10.2, U2.51 (PA15), U5.4 (SCK)
/I2C1_SDA: R11.2, U2.60 (PB7), U5.3 (SDI)
/IMU_INT1: U2.30 (PB10), U4.4 (INT1)
/LED1: R15.2, U2.24 (PB0)
/LED2: R16.2, U2.25 (PB1)
/LED3: R17.2, U2.26 (PB2)
/LED4: R18.2, U2.22 (PC4)
/NRST: C13.1, D1.2 (A2), J5.10, SW1.2, U2.7 (PG10)
/PG: R3.2, U1.8 (PG)
/SPI1_CS: U2.18 (PA4), U4.12 (CSB)
/SPI1_MISO: U2.20 (PA6), U4.1 (SDO)
/SPI1_MOSI: U2.21 (PA7), U4.14 (SDX)
/SPI1_SCK: U2.19 (PA5), U4.13 (SCX)
/SWCLK: J5.4, U2.50 (PA14)
/SWDIO: J5.2, U2.49 (PA13)
/SWO: J5.6, U2.56 (PB3)
/USART2_RX: J6.4, U2.17 (PA3)
/USART2_TX: J6.3, U2.14 (PA2)
/USB_DM: U2.45 (PA11), U3.4 (I/O2)
/USB_DM_RAW: J2.A7 (D-), J2.B7 (D-), U3.3 (I/O2)
/USB_DP: U2.46 (PA12), U3.6 (I/O1)
/USB_DP_RAW: J2.A6 (D+), J2.B6 (D+), U3.1 (I/O1)
/VDDA: C4.2, C5.2, R5.1, R6.1, U2.29 (VDDA)
GND: C1.2, C2.2, C3.1, C4.1, C5.1, C6.2, C7.2, C8.2, C9.2, C10.2, C11.2, C12.2, C13.2, C14.2, C15.2, C16.2, C17.2, C18.2, C19.2, C20.2, C21.2, C22.2, D1.1 (A1), D2.3, D3.1 (K), D4.1 (K), D5.1 (K), D6.1 (K), J2.A1 (GND), J2.A12 (GND), J2.B1 (GND), J2.B12 (GND), J2.S1 (SHIELD), J3.3, J5.3, J5.5, J5.9, J6.1, R2.2, R7.2, R8.2, R9.1, R12.1, R13.1, SW1.1, SW2.1, U1.1 (PGND), U1.4 (AGND), U2.15 (VSS), U2.27 (VSSA), U2.31 (VSS), U2.47 (VSS), U2.63 (VSS), U3.2 (GND), U4.6 (GNDIO), U4.7 (GND), U5.1 (GND), U5.5 (SDO), U5.7 (GND), U6.2 (GND)
unnamed: D3.2 (A), R15.1
unnamed: D4.2 (A), R16.1
unnamed: D5.2 (A), R17.1
unnamed: D6.2 (A), R18.1
unnamed: J2.A5 (CC1), R9.2
unnamed: J2.B5 (CC2), R8.1
unnamed: J4.1, R14.2
unnamed: R1.2, R2.1, U1.5 (FB)
unnamed: L1.1, U1.7 (SW)
unnamed: C3.2, R4.2, U2.1 (VBAT)
unnamed: C6.1, C7.1, R6.2, U2.28 (VREF+)
unnamed: R12.2, U6.5 (SHDN)
unnamed: R13.2, U6.8 (STB)

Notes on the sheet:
BOOT0 jumper (J1) = boot mode selector
POWER INPUT & 3.3V REGULATION USB-C VBUS (5V) → TPS62160 buck → 3.3V @ 1A
USER I/O & DEBUG: Status LEDs (D3-D6) on PC0-PC3, user button (SW2) on PC13, SWD header (J5) on PA13/PA14 + PB3 SWO, UART2 header (J6) on PA2/PA3
ENVIRONMENTAL SENSOR BME280 over I2C1 (addr 0x76) - temperature / pressure / humidity
USB-C DATA INTERFACE Type-C receptacle (J2) + USBLC6-2P6 ESD protection + 5.1kΩ CC pulldowns (UFP/sink mode) → STM32 USB FS (PA11/PA12)
end-of-bus enable
CAN FD TRANSCEIVER TCAN334GDR on FDCAN2 (PB5/PB6) + switchable 120Ω termination (J4) + PESD2CANFD27V TVS + 3-pin pluggable bus connector (J3)
SDO→GND = I2C addr 0x76 strap
MCU STM32G474RET6 - 170MHz Cortex-M4, 512KB Flash, FDCAN, USB FS + reset (SW1/NRST) + BOOT0 jumper (J1) + VDD/VDDA decoupling
6-AXIS IMU BMI270 over SPI1 (PA4 CS / PA5 SCK / PA6 MISO / PA7 MOSI) + INT1 on PB10

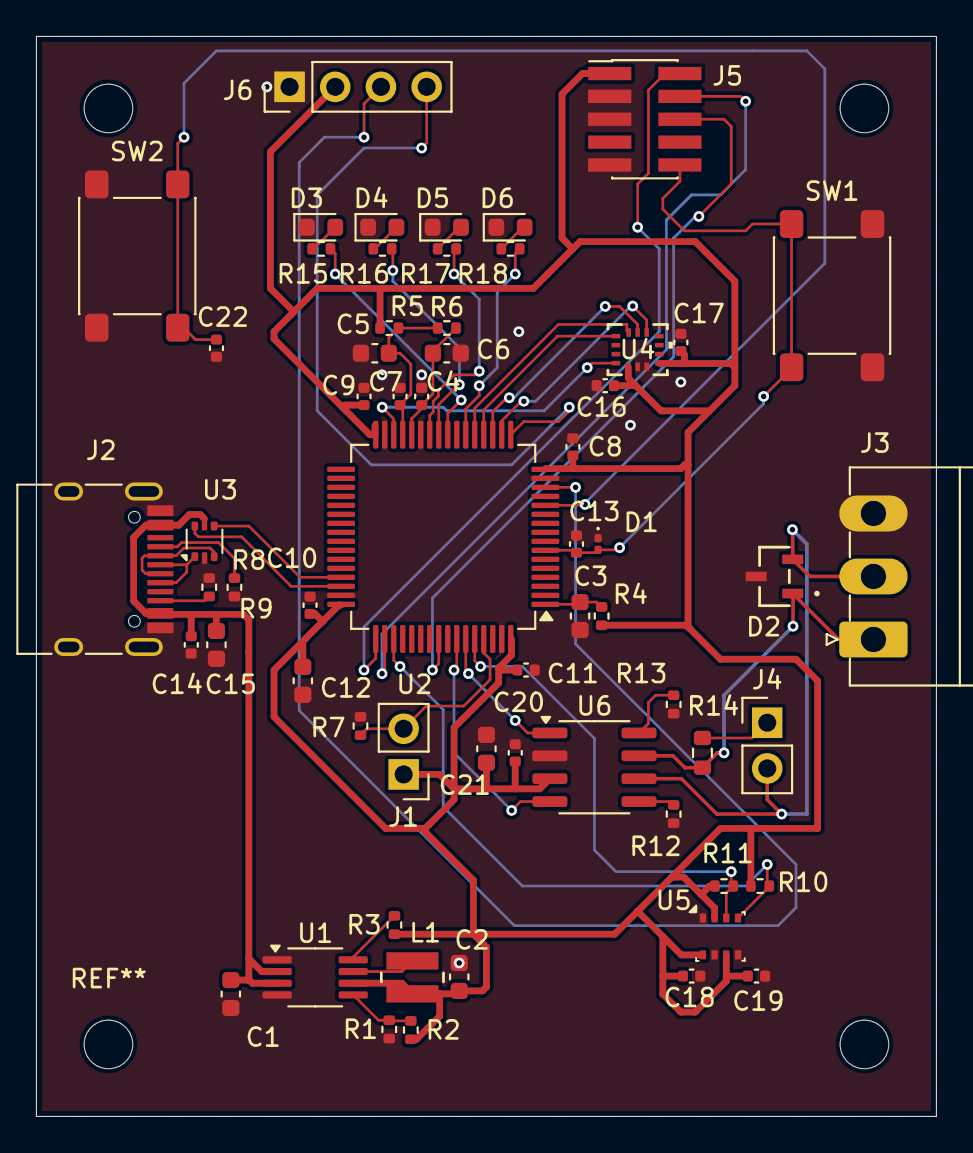
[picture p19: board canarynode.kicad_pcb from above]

Board: 4 copper layers, 50.0 x 60.0 mm, 61 parts (0 on the bottom side), 45 nets.

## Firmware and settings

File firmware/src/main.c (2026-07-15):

//looks in the vendor/cmsis from CMakeLists
#include <stdint.h>
#include "bme280.h" 
#include "i2c.h"
#include "fdcan.h"
#include "blink.h"

int main(void) {

    // -- Peripheral bring-up (buses + LED pin) --
    led_init(); //PA5 -> output, LED off
    i2c_init(); //i2c1 master on PB8/PB9 must come before sensor access
    fdcan_init(); //FDCAN1 @500k, internal loopback

    // --- FDCAN Test ---
    // Send a frame, in loopback it comes straight bazck to our own RX FIFO
    //test for Tx, id=0x123, d0,     d1
    fdcan_send(0x123, 0xDEADBEEF, 0x12345678);
    //initialize varibles to write into
    //volatile because main never reads these, they exist for the debugger
    volatile uint32_t id, dlc, d0, d1;
    //send the locations of each variable 
    fdcan_recv(&id, &dlc, &d0, &d1);

    // -- I2C + BME280 Smoke Test -- 
    // bme280_init() reads chip ID 0xD0: returns 0 if it == 0x60, else 1
    uint8_t bme_status = bme280_init();

    // Fail Trap:
    // On failure: light the LED solid and halt, before TIM6 ever starts
    // Because timer never runs the ISR never fires, nothing toggles
    // PA5 -> LED stays solid will fail
    if (bme_status != 0) {
        led_on();
        while(1) {}
    }

    // -- reached only on succcess -- 
    // It is safe to read now, the bus is known-good
    // volatile because inspected by GDB not read by code
    volatile bme280_reading_t reading;

    // -- PASS: start the heartbeat --
    tim6_init();

    // re-read forever so live values apppear in the debugger
    while (1) {
        reading = bme280_read();
        volatile float temp_c    = reading.temperature / 100.0f;   // C
        volatile float press_hpa = reading.pressure    / 25600.0f;  // hPa
        volatile float hum_rh    = reading.humidity    / 1024.0f;   // %RH
        for (volatile int i = 0; i < 400000; i++);                  // pace (a few reads/sec)
    }
}

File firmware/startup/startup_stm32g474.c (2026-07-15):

//Part 1: include and extern declarations
#include <stdint.h>

//linker defined variables, extern: declare a name without defining it
extern uint32_t _sdata[]; //start of .data, defined in linker inside SECTIONS
extern uint32_t _edata[]; //end of .data section in RAM
extern uint32_t _sidata[]; //load address of .data section in flash, defined via LOADADDR(.data)
extern uint32_t _sbss[]; //start of .bss in RAM. defined in the .bss SECTIONS in linker
extern uint32_t _ebss[]; //end of .bss in RAM
extern uint32_t _estack[]; //top of RAM, defined at botto of linker

//Part 2: Forward declarations

//reset handler function
void Reset_Handler(void);

//default handler used until we write out other handlers
void Default_Handler(void);

//main function, must be called before called in src/main.c 
int main(void);

//TIM6 update interrupt - body defined in main.c
void TIM6_DAC_IRQHandler(void);

//Part 3: Vector table

//Tells compiler 'put this variable or function in th names output section
//forces vector table into .isr_vector
//name in attribute and one in linker must match
//const keeps the table in flash
//vector_table is an array of function(const) pointers
//C decays each Handler function to a pointer to a function pointer
__attribute__((section(".isr_vector")))
void (* const vector_table[])(void) = {
    (void (*)(void))_estack,    // 0x00: initial SP
    Reset_Handler,              // 0x04: reset
    Default_Handler,            // 0x08: NMI
    Default_Handler,            // 0x0C: HardFault
    Default_Handler,            // 0x10: MemManage
    Default_Handler,            // 0x14: BusFault
    Default_Handler,            // 0x18: UsageFault
    0, 0, 0, 0,                 // 0x1C-0x28: reserved
    Default_Handler,            // 0x2C: SVCall
    Default_Handler,            // 0x30: DebugMon
    0,                          // 0x34 reserved
    Default_Handler,            // 0x38: PendSV
    Default_Handler,            // 0x3C: SysTick
    [16 ... 69] = Default_Handler, //peripherals not assigned
    [70] = TIM6_DAC_IRQHandler,    //defined in main- stm defined TIM6 IRQ=54 so 54+16=70
};

// Runs first on power-on. sets up C runtime, then calls main
// noreturn = compiler knows this never returns
__attribute__((noreturn))
void Reset_Handler(void)
{
    // Enable the FPU before any float instruction runs.
    // Build uses -mfloat-abi=hard, so the compiler emits FPU ops; without turning
    // the FPU on, the first one HardFaults. CPACR (SCB, 0xE000ED88) bits [23:20] =
    // CP10/CP11 full access. (This is what CMSIS SystemInit normally does)
    *(volatile uint32_t *)0xE000ED88 |= (0xFUL << 20);
    __asm volatile ("dsb");
    __asm volatile ("isb");

    //copy .data from flash to RAM
    uint32_t *src = _sidata; //flash source: init values stored here
    uint32_t *dst = _sdata;  //RAM destination
    while (dst < _edata) {    //walk until end of .data in ram
        *dst++ = *src++;     //copy 4 bytes and advance both pointers
    }

    //zero .bss - C gauruntees unitizialted globals start at 0
    dst = _sbss;            //reuse dst pointer
    while (dst < _ebss) {   //walk the .bss range in RAM
        *dst++ = 0;         // write zero, advance
    }

    //call main
    main();

    //if main returns hang, defensive
    while (1) { }
}

//catch all unconfigured interrupt vectors
//weak = real handelers (defined elswhere) override this
//early dev spec
__attribute__((weak, noreturn))
void Default_Handler(void) 
{
    while (1) { }
}

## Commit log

2026-05-21 Initial commit: week 1 deliverables (block diagram, power tree, pin map, BOM scaffold, KiCad project)
    [canarynode.kicad_pcb, canarynode.kicad_sch]
2026-05-21 Ignore KiCad lock files
2026-05-21 Add Nucleo-G474RE reference schematic; library and tooling setup complete
2026-05-21 Pre-KiCad audit: CAN FD swap, IMU INT1 wiring, TCAN334G mode pins, VBAT/VREF TODOs
2026-05-21 schematic: TPS62160 buck subcircuit complete (5V to 3.3V/1A)
    TPS62160DGKR adjustable buck, VSSOP-8 (C60726)
    - L=3.3uH XFL3012-332MEC for low-VIN operation per datasheet 9.2.2.4
    - C1=10uF/10V X5R 0603 (C19702), C2=22uF/6.3V X5R 0603 (C59461)
    - FB divider: R1=562k, R2=180k for Vout=3.30V per Eq 6 (Vref=0.8V)
    - R3=100k PG pull-up to +3.3V; PG net labeled for future GPIO/test point
    - VOS routed to VOUT at output cap per 11.1 layout guidance
    - PGND/AGND single-point ground at IC
    - PWR_FLAGs on +5V, +3.3V, GND
    - Footprints: KiCad built-ins + Coilcraft_Local for XFL3012
    - ERC: 0 errors
    [canarynode.kicad_sch]
2026-05-24 schematic: STM32G474 MCU subcircuit complete
    - U2 STM32G474RET6 in LQFP-64 (C521608)
    - Decoupling per datasheet Fig 16 + Nucleo MB1367
    - 4x 100nF + 4.7uF bulk on VDD pins 16/32/48/64
    - 100nF + 1uF on VDDA (Nucleo divergence: datasheet says 10nF)
    - 100nF + 1uF on VREF+
    - 1uF on VBAT
    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
2026-05-24 schematic: add USB-C subcircuit (J2, U3, R8/R9, C14/C15)
    [canarynode.kicad_sch]
2026-05-24 Add BME280 environmental sensor (U5, I2C1, addr 0x76)
    [canarynode.kicad_sch]
2026-05-24 Add CAN FD bus: TCAN334G transceiver, 120Ω switchable termination, PESD2CANFD27V TVS, 3.5mm screw terminal
    [canarynode.kicad_sch]
2026-05-25 Add LEDs, button, SWD header, UART header
    [canarynode.kicad_sch]
2026-05-25 v1.0-schematic-complete: pre-layout validation done
    - All 9 validation categories cleared
    - Footprint fixes: J3 drill 1.4mm, SW1/SW2 swap to C6630024
    - I2C1 pin assignment corrected to PA15/PB7
    - Board outline 50x60mm, SIG/GND/GND/SIG stackup
    - BOM finalized, 61 components
    [canarynode-bom.csv, canarynode.csv, canarynode.kicad_pcb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]
2026-05-25 docs(sch): add annotation labels for J1 BOOT0, J4 CAN term, BME280 addr strap
    [canarynode.kicad_sch]
2026-05-26 pcb: configure board setup - layers (SIG/GND/GND/SIG), net classes, DRC constraints
    [canarynode.kicad_pcb]
2026-05-26 pcb: place edge connectors, MCU, ICs, buck/CAN/MCU decoupling clusters
    [canarynode.kicad_pcb]
2026-05-28 pcb: complete component placement — all 61 placed, DRC clean (unrouted)
    [canarynode.kicad_pcb]
2026-05-30 pcb: stitch GND island vias, silkscreen cleanup, DRC clean
    [canarynode.kicad_pcb]
2026-05-30 fab: generate gerbers + drill files for JLC
    [canarynode-B_Mask.gbr, canarynode-B_Paste.gbr, canarynode-B_Silkscreen.gbr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]
2026-05-30 fab: add LCSC to BOM, generate CPL, exclude mounting holes from placement, remove stale datasheet
    [canarynode.csv, canarynode.kicad_pcb, canarynode.kicad_sch]
2026-06-12 Add firmware tree; update PCB layout and BOM
    [canarynode.csv, canarynode.kicad_pcb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]
2026-06-18 initial blink LED
    [canarynode.kicad_sch]
2026-07-01 FDCAN: refactor into fdcan_init/send/recv; add PA11/PA12 pin config
2026-07-06 I2C1: master init + read/write/burst register primitives
2026-07-07 Modularize: split I2C into i2c.c/.h, add BME280 driver (init + calib)
2026-07-08 Finish BME280 driver (read + compensation); split blink/fdcan/i2c/bme280 into modules; add smoke-test harness in main
2026-07-15 Add live BME280 readout: hardware-verified T/P/H over I2C, GDB stream
2026-07-21 SPI init bringup
2026-07-22 spi.c completed and built
2026-07-29 bmi driver & config
2026-09-08 Port firmware to custom board, update README
    Custom PCB is alive: powers up, enumerates as a DFU device over USB-C,
    and takes a verified flash write with no debugger attached.
    - Linker flash length 512K -> 256K for the RCT6
    - blink.c: LED moved from PA5 to PB0
    - i2c.c: I2C1 remapped to PA15 (SCL) / PB7 (SDA), both AF4, split across
    two ports so both GPIO clocks are enabled. BME280 chip ID verified on
    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
2026-10-27 Fix BMI270 SPI bring-up: add idle time after the I2C-to-SPI dummy reads
    The chip never answered over SPI (MISO floating). Isolated it on the board with LED readouts: pull-up test, pin test, bit-banged I2C and SPI, then the real driver after a pause. Hardware and SPI peripheral were fine; the driver issued the real read immediately after the mode-switch dummy read. Added ~1 ms idle after both dummy reads (DS t_IDLE_rd). Full init including the 8 KB config upload and init_ok now passes on the custom board.
